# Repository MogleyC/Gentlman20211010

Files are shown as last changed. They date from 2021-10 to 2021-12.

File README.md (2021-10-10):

# Gentlman20211010

해당 제작물의 모든 소유권(소스,정보,파일,개발과정 등)은 (주)프시케가 갖는다.
(주)프시케에서 지정한 소속 관리자 외 일체의 열람/복사/사용을 금한다.
무단 열람/복사/사용이 되는 경우 해당 개인/단체에 법적 책임을 물을 수 있다.
이 외 상세사항 및 권한변경은 (주)프시케의 내부규정에 의거한다.

Gentlman20211010는 주로 Gentlman V6.3을 개발/관리를 위해 제작되었다.
Gentlman V6.3의 주 개발 목표는 다음과 같다.
 - V6.2를 베이스로 한 V6.3 PCB 설계 및 아트웤
 - 무료 툴인 KiCAD를 이용, 툴의 숙달 및 결과물 제작
 - V6.3에 맞는 펌웨어 제작
 - 블루투스 버전인 V6.3B의 개발

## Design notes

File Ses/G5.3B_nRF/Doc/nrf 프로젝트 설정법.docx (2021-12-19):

주간 업무 일지

2021년 12월 6일 ~ 12월 10일

연구개발소장 강신구

# I. 신규 프로젝트 생성 및 설정

## New Solution

### 아무 프로젝트를 만들고 솔루션에서 프로젝트를 remove한다.

### 이후 폴더내에 .emProject 파일을 제외하고 모두 삭제한다.

## New Project

### C/C++ executable for Nordic Semiconductor nRF

### Target Processor : nRF52832_xxAA or nRF52810_xxAA

### Compiler : gcc

### Additional Output Format : hex

### Select files to add to project : Files 및 Import all files and package files 체크 해제. nRF5_SDK파일들을 이용한다.

## Base Project Setting

### Solution or Project → Open Solution in Editor → <project Name>과 </project>사이를 수정

#### 붉은색은 프로젝트 버전 및 nRF칩셋에 맞게 반드시 수정(아래는 nRF52832으로 설정)

#### 연녹색은 소프트디바이스용

<configuration

Name="Common"

arm_architecture="v7EM"

arm_core_type="Cortex-M4"

arm_endian="Little"

arm_fp_abi="Hard"

arm_fpu_type="FPv4-SP-D16"

arm_linker_heap_size="2048"

arm_linker_process_stack_size="0"

arm_linker_stack_size="2048"

arm_linker_treat_warnings_as_errors="No"

arm_simulator_memory_simulation_parameter="RWX 00000000,00100000,FFFFFFFF;RWX 20000000,00010000,CDCDCDCD"

arm_target_device_name="nRF52832_xxAA"

arm_target_interface_type="SWD"

c_preprocessor_definitions="NRF52832_XXAA;NRF52;NRF52_PAN_74;FLOAT_ABI_HARD;CONFIG_GPIO_AS_PINRESET;INITIALIZE_USER_SECTIONS;

c_user_include_directories="$(nRFSdkPath)/modules/nrfx/mdk;$(nRFSdkPath)/components/toolchain/cmsis/include;$(SrcPath);$(SrcPath)/$(nRFSdkVer);"

debug_additional_load_file="$(nRFSdkPath)/components/softdevice/s112/hex/s112_nrf52_7.2.0_softdevice.hex"

debug_register_definition_file="$(nRFSdkPath)/modules/nrfx/mdk/nrf52.svd"

debug_start_from_entry_point_symbol="No"

debug_target_connection="J-Link"

gcc_debugging_level="Level 3"

gcc_entry_point="Reset_Handler"

linker_output_format="hex"

linker_printf_fmt_level="long"

linker_printf_width_precision_supported="Yes"

linker_scanf_fmt_level="long"

linker_section_placement_file="$(nRFSdkPath)/config/$(nRFSdkVer)/ses/flash_placement.xml"

linker_section_placement_macros="FLASH_PH_START=0x0;FLASH_PH_SIZE=0x80000;RAM_PH_START=0x20000000;RAM_PH_SIZE=0x10000;FLASH_START=0x19000;FLASH_SIZE=0x67000;RAM_START=0x200022c8;RAM_SIZE=0xdd38"

linker_section_placements_segments="FLASH1 RX 0x0 0x80000;RAM1 RWX 0x20000000 0x10000"

macros="nRFSdkVer=nrf52832;nRFSdkPath=../../../nRF5_SDK;SrcPath=../../SRC;CMSIS_CONFIG_TOOL=../../../../../../external_tools/cmsisconfig/CMSIS_Configuration_Wizard.jar"

project_directory="nRF52832"

project_type="Executable" />

<folder Name="System Files">

<file file_name="$(StudioDir)/source/thumb_crt0.s" />

<file file_name="$(nRFSdkPath)/modules/nrfx/mdk/ses_startup_nrf52.s" />

<file file_name="$(nRFSdkPath)/modules/nrfx/mdk/ses_startup_nrf_common.s" />

<file file_name="$(nRFSdkPath)/modules/nrfx/mdk/system_nrf52.c" />

</folder>

<folder Name="Application">

<file file_name="$(SrcPath)/main.c" />

<file file_name="$(SrcPath)/$(nRFSdkVer)/sdk_config.h" />

<file file_name="$(SrcPath)/board_config.h" />

</folder>

</project>

## nRF5_SDK용 config setting

### 다음의 두개의 파일을 복사

#### nRF5_SDK 폴더/config/칩셋종류/config/sdk_config.h

#### nRF5_SDK 폴더/config/칩셋종류/ses/flash_placement.xml

### 다음의 위치에 붙여넣기

#### SRC/칩셋종류/

### sdk_config.h의 사용하는 칩셋/모듈에 따라 셋팅 값을 조정해 주어야 한다.

# II. nRF52810 vs nRF52832 셋팅 차이

## 타겟 칩셋 설정

### Project Option → Debugger

#### Target Device : nRF52810_xxAA / nRF52832_xxAA

#### Register Definition File

##### nRF52810 : $(nRFSdkPath)/modules/nrfx/mdk/nrf52810.svd

##### nRF52832 : $(nRFSdkPath)/modules/nrfx/mdk/nrf52.svd

## FPU(부동소수점 유닛)의 유무에 따른 설정

### Project Option → Code Generation

#### ARM FP ABI Type : Soft(nRF52810) / Hard(nRF52832)

#### ARM FPU Type : None(nRF52810) / FPv4-SP-D16(nRF52832)

## 메모리 설정

### Project Option → Runtime Memory Area

#### Heap Size : 2048

#### Main Stack Size : 2048

#### Process Stack Size : 0

#### 위 설정들은 공용으로 사용할 수 있으며, 필요에 따라 칩셋에 맞게 수정한다.

### Project Option → Linker

#### Memory Segments

##### nRF52810 : FLASH1 RX 0x0 0x30000;RAM1 RWX 0x20000000 0x6000

##### nRF52832 : FLASH1 RX 0x0 0x80000;RAM1 RWX 0x20000000 0x10000

#### Memory Placement File

##### $(nRFSdkPath)/config/$(nRFSdkVer)/ses/flash_placement.xml

##### $(nRFSdkVer) 메크로가 제대로 설정되었는지 확인 필요

#### Memory Placement Macros

##### nRF52810 : FLASH_PH_START=0x0;FLASH_PH_SIZE=0x30000;RAM_PH_START=0x20000000;RAM_PH_SIZE=0x6000;FLASH_START=0x19000;FLASH_SIZE=0x17000;RAM_START=0x200022c8;RAM_SIZE=0x3d38

##### nRF52832 : FLASH_PH_START=0x0;FLASH_PH_SIZE=0x80000;RAM_PH_START=0x20000000;RAM_PH_SIZE=0x10000;FLASH_START=0x19000;FLASH_SIZE=0x67000;RAM_START=0x200022c8;RAM_SIZE=0xdd38

## 정의 설정

#### Project Option → Preprocessor → Preprocessor Includes

##### nRF52810 : NRF52810_XXAA;DEVELOP_IN_NRF52832;FLOAT_ABI_SOFT;NRFX_COREDEP_DELAY_US_LOOP_CYCLES=3;

##### nRF52832 : NRF52832_XXAA;NRF52;FLOAT_ABI_HARD;

##### 설정에 맞게 위를 포함시켜야 함

## 시스템 파일 설정

### system file in nRF52810

#### $(nRFSdkPath)/modules/nrfx/mdk/ses_startup_nrf52810.s

#### $(nRFSdkPath)/modules/nrfx/mdk/system_nrf52810.c

### system file in nRF52832

#### $(nRFSdkPath)/modules/nrfx/mdk/ses_startup_nrf52.s

#### $(nRFSdkPath)/modules/nrfx/mdk/system_nrf52.c

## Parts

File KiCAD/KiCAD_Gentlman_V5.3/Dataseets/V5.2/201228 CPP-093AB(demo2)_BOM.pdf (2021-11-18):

Description | Comment | TYPE | MAKER | Quantity | Designator
CHIP CERAMIC CAP | 101K/250V | 2012 | WALSIN, SAMSUNG | 14 | C17, C19, C24, C25, C26, C27, C28, C29, C31, C32, C36, C37, C39, C40
CHIP CERAMIC CAP | 103K/25V | 1608 | WALSIN, SAMSUNG | 0 | C11, C12
CHIP CERAMIC CAP | 103K/25V | 1608 | WALSIN, SAMSUNG | 5 | C23, C38, C45, C50, C51
CHIP CERAMIC CAP | 104Z/25V | 1608 | WALSIN, SAMSUNG | 8 | C1, C2, C3, C4, C5, C7, C13, C14
CHIP CERAMIC CAP | 105Z/6.3V | 1608 | WALSIN, SAMSUNG | 1 | C8
CHIP CERAMIC CAP | 105Z/6.3V | 1608 | WALSIN, SAMSUNG | 0 | C9, C10
CHIP CERAMIC CAP | FS43X105K251EGG | 4532 | WALSIN | 8 | C21, C22, C34, C35, C43, C44, C48, C49
CHIP CERAMIC CAP | TCC1206X7R103K251DT | 3216 | CCTC | 4 | C20, C33, C42, C47
CHIP LED RED | WR106SR-W | 1608 | BRIGHT LED | 7 | D1, D2, D3, D4, D5, D6, D7
CHIP LED RGB | BL-HBHG8JE36K-TRB-T05 | 1615 | BRIGHT LED | 5 | RGB1, RGB2, RGB3, RGB4, RGB5
CHIP RESISTOR | 0RJ | 6432 | WALSIN, SAMSUNG | 1 | R138
CHIP RESISTOR | 1KF | 1608 | WALSIN, SAMSUNG | 29 | .
CHIP RESISTOR | 1KF | 1608 | WALSIN, SAMSUNG | 0 | R23, R24
CHIP RESISTOR | 2.7KF | 1608 | WALSIN, SAMSUNG | 12 | R34, R35, R36, R37, R56, R57, R58, R62, R63, R64, R65, R68
CHIP RESISTOR | 4.7KF | 1608 | WALSIN, SAMSUNG | 2 | R26, R27
CHIP RESISTOR | 8.2KF | 1608 | WALSIN, SAMSUNG | 4 | R45, R71, R95, R125
CHIP RESISTOR | 10KJ | 1608 | WALSIN, SAMSUNG | 1 | R1
CHIP RESISTOR | 10KJ | 1608 | WALSIN, SAMSUNG | 0 | R20, R21, R22
CHIP RESISTOR | 22KJ | 1608 | WALSIN, SAMSUNG | 0 | R25
CHIP RESISTOR | 47RJ | 1608 | WALSIN, SAMSUNG | 5 | R15, R16, R17, R18, R19
CHIP RESISTOR | 100KJ | 1608 | WALSIN, SAMSUNG | 52 | R32, R33, R39, R40, R44, R46, R48, R49, R51, R54, R55, R60, R61, R70, R72, R74, R75, R77, R80, R81, R82, R83, R85, R86, R87, R88, R94, R96, R98, R99, R101, R102, R104, R105, R107, R110, R111, R112, R113, R115, R116, R117, R118, R124, R126, R128, R129, R131, R132, R134, R135, R137
CHIP RESISTOR | 100RJ | 1608 | WALSIN, SAMSUNG | 4 | R43, R69, R93, R123
CHIP RESISTOR | 120RJ | 3216 | WALSIN, SAMSUNG | 4 | R31, R53, R79, R109
CHIP RESISTOR | 150KF | 2012 | WALSIN, SAMSUNG | 8 | R30, R38, R52, R59, R78, R84, R108, R114
CHIP RESISTOR | 270RF | 1608 | WALSIN, SAMSUNG | 1 | R28
CHIP RESISTOR | 390RJ | 1608 | WALSIN, SAMSUNG | 6 | R2, R3, R4, R5, R6, R7
CHIP RESISTOR | 510RF | 1608 | WALSIN, SAMSUNG | 1 | R29
CHIP TRANSISTOR | 2N5401S | SOT-23 | FIRST SILICON | 12 | Q7, Q8, Q13, Q14, Q19, Q20, Q21, Q22, Q31, Q32, Q33, Q34
CHIP TRANSISTOR | 2N5551S | SOT-23 | FIRST SILICON | 24 | Q9, Q10, Q11, Q12, Q15, Q16, Q17, Q18, Q23, Q24, Q25, Q26, Q27, Q28, Q29, Q30, Q35, Q36, Q37, Q38, Q39, Q40, Q41, Q42
CHIP TRANSISTOR | 2SA1981SY | SOT-23 | AUK | 6 | Q1, Q2, Q3, Q4, Q5, Q6
PIN HEADER | SMW2.5MM-7P | DIP-8 | YEONHO ELECTRONICS | 0 | CN1
SMD AMPLIFIER 1W | AP4890 | SOP8 | APLUS | 0 | U4
SMD BUFFER | ULN2003D1013TR | SOP-16 | STMicroelectronics | 1 | U5
SMD DIODE SCHOTTKY | MBRAF3200T3G | SMA | MDD, ON SEMICONDUCTOR | 4 | D8, D9, D10, D11
SMD DIODE TVS | SMBJ15A | SMB | SAMYANG ELECTRONICS | 1 | TVS1
SMD ELECT CAPACITOR | 220uF/6.3V | SC 6.3X5.8 | SAMYOUNG | 7 | C6, C15, C16, C18, C30, C41, C46
SMD INDUCTOR | SC7850D-221K | 7850 | SUHKWANG | 4 | L1, L2, L3, L4
SMD JACK USB C TYPE | USB-TYPE-C-31-M-17 | SMD-6 | Korean-Hroparts-Elec | 1 | CN4
SMD MCU | STM32G070RBT6 | LQFP64 | STMicroelectronics | 1 | U1
SMD MOSFET N-CHANNEL | FDT86246L | SOT223 | FAIRCHILD | 4 | FET1, FET2, FET3, FET4
SMD REGULATOR | LMT117-ADJ | SOT-223 | TGS | 1 | U6
SMD SERIAL FLASH | W25Q32JVSSIQ | SOIC-8(208mil) | WINBOND | 0 | U2
SMD VOICE | VLN1MM04S8X | SOP-8 | SYNOOS | 1 | U3
SMD WAFER | 12505WR-02 | SMD-2 | YEONHO ELECTRONICS | 1 | CN2
SMD WAFER | 12505WR-02 | SMD-2 | YEONHO ELECTRONICS | 0 | CN3
SMD WAFER | 12505WS-08(STRAIGHT) | SMD-8 | YEONHO ELECTRONICS | 1 | CN6
SMD WAFER | 12505WS-09(STRAIGHT) | SMD-9 | YEONHO ELECTRONICS | 1 | CN5
SPEAKER | TDM15A-8-L055C0.5S-0.3D | ASS'Y | NCEI | 1 | SPK1

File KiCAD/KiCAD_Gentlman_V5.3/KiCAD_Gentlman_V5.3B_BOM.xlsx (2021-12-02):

Reference | Quantity | Value | Footprint | Datasheet | Comment | Description | Field4 | MAKER | TYPE | Field5 | PartName | Shop
ANT1 | 1 | ANT | Custom:ANT_PATTERN | .\Dataseets\001-91445_AN91445_Antenna_Design_and_RF_Layout_Guidelines.pdf |  |  | PATTERN
C17 C19 C24 C25 C26 C27 C28 C29 C31 C32 C36 C37 C39 C40 | 14 | CAP_101K_250V_2012 | Custom:C_0805_2012Metric | ~ | CC0805JRNPOYBN101 | CHIP CERAMIC CAP | 101K/250V | YAGEO | 2012 |  |  | https://www.eleparts.co.kr/goods/view?no=9594793
C20 C33 C42 C47 | 4 | CAP_103K_250V_3216 | Custom:C_1206_3216Metric | .\Dataseets\TCC1206X7R103K251DT_10nF_250V_K.pdf | TCC1206X7R103K251DT | CHIP CERAMIC CAP | TCC1206X7R103K251DT | CCTC | 3216 |  |  | https://www.eleparts.co.kr/goods/view?no=8016042
C21 C22 C34 C35 C43 C44 C48 C49 | 8 | CAP_105K_250V_4532 | Custom:C_1812_4532Metric | .\Dataseets\FS43X105K251EGG_1uF_250V_K.pdf | FS43X105K251EGG | CHIP CERAMIC CAP | FS43X105K251EGG | WALSIN | 4532 |  |  | https://www.eleparts.co.kr/goods/view?no=8016951
C23 C38 C45 C50 C51 | 5 | CAP_103K_25V_1608 | Custom:C_0603_1608Metric | ~ | CC0603KRX7R8BB103 | CHIP CERAMIC CAP | 103K/25V | YAGEO | 1608 |  |  | https://www.eleparts.co.kr/goods/view?no=8057789#goodContent_3
C1 C2 C3 C4 C7 C13 C14 | 7 | CAP_104Z_25V_1608 | Custom:C_0603_1608Metric | ~ | CL10B104KA8NNNC | CHIP CERAMIC CAP | 104Z/25V | SAMSUNG ELECTRO-MECHANICS | 1608 |  |  | https://www.eleparts.co.kr/goods/view?no=8010066
C54 | 1 | CAP_4.7uF_1005 | Custom:C_0402_1005Metric | .\Dataseets\MLCC-1837944.pdf | CL05A475KP5NRNC | CHIP CERAMIC CAP | 4.7uF/짹10 | SAMSUNG ELECTRO-MECHANICS | 1005 |  | CL05A475KQ5NRNC | https://www.eleparts.co.kr/goods/view?no=8057798
C56 | 1 | CAP_N.C_1005 | Custom:C_0402_1005Metric | ~ | N.C | CHIP CERAMIC CAP | N.C | MURATA ELECTRONICS | 1005
C52 C53 C55 C57 | 4 | CAP_100nF_1005 | Custom:C_0402_1005Metric | .\Dataseets\GRM155R61H104KE14_01A-1983917.pdf | CL05A104KA5NNNC | CHIP CERAMIC CAP | 100nF/짹10 | SAMSUNG ELECTRO-MECHANICS | 1005 |  | GRM155R61H104KE14D | https://www.eleparts.co.kr/goods/view?no=8011439
C58 | 1 | CAP_1uF_1005 | Custom:C_0402_1005Metric | .\Dataseets\Samsung_MLCC_1837944-1929650.pdf | CL05A105KA5NQNC | CHIP CERAMIC CAP | 1uF/짹10 | SAMSUNG ELECTRO-MECHANICS | 1005 |  | CL05A105KP5NNWC | https://www.eleparts.co.kr/goods/view?no=8010445
C6 C15 C16 C18 C30 C41 C46 | 7 | CAP_220uF_6.3V_SC6.3X5.8 | Custom:C_Elec_6.3x5.8 | ~ | 220uF/6.3V | SMD ELECT CAPACITOR | 220uF/6.3V | SAMYOUNG | SC 6.3X5.8 | SC 6.3X5.8 |  | https://www.eleparts.co.kr/goods/view?no=3369557
C59 C60 | 2 | CAP_12pF_1005 | Custom:C_0402_1005Metric | .\Dataseets\GRM1555C1H120GA01_01A-1982688.pdf | 0402N120G250CT | CHIP CERAMIC CAP | 12pF/NP0/짹2 | WALSIN | 1005 |  | GRM1555C1H120GA01D | https://www.eleparts.co.kr/goods/view?no=9226620
C61 | 1 | CAP_0.8pF_1005 | Custom:C_0402_1005Metric | .\Dataseets\GRM1555C1HR80WA01_01A-1983059.pdf | GRM1555C1HR80WA01D | CHIP CERAMIC CAP | 0.8pF/NP0/짹5 | MURATA ELECTRONICS | 1005 |  | GRM1555C1HR80WA01D | https://www.eleparts.co.kr/goods/view?no=9591919
D1 D2 D3 D4 D5 D6 D7 | 7 | WR106SR-W | Custom:LED_0603_1608Metric | .\Dataseets\WR106SR-W.pdf | WR106SR-W | CHIP LED RED |  | BRIGHT LED | 1608 |  |  | https://www.eleparts.co.kr/goods/view?no=8104608
D8 D9 D10 D11 | 4 | MBRAF3200T3G | Custom:D_SMA | .\Dataseets\MBRAF3200T3_D-2315037.pdf | SS1200-LTP | SMD DIODE SCHOTTKY |  | Micro Commercial | SMA |  |  | https://www.eleparts.co.kr/goods/view?no=1799117
FET1 FET2 FET3 FET4 | 4 | FDT86246L | Custom:SOT-223-3_TabPin2 | .\Dataseets\FDT86246L-D.pdf | FDT86246L | SMD MOSFET N-CHANNEL |  | FAIRCHILD | SOT-223 |  |  | https://www.eleparts.co.kr/goods/view?no=6008399
J1 | 1 | PinHeader2.54mm_7 | Custom:PinHeader_1x07_P2.54mm_Vertical | ~ | PinHeader2.54mm-7P | PIN HEADER | DOWNLOAD | YEONHO ELECTRONICS | DIP-7
J2 | 1 | 12505WR-02 | Custom:12505WR-02 | .\Dataseets\12505-NN.pdf | 12505WR-02 | SMD WAFER | SPEAK1 | YEONHO ELECTRONICS | SMD-2 |  |  | https://www.devicemart.co.kr/goods/view?no=1381566
J4 | 1 | USB-TYPE-C-31-M-17 | Custom:TYPE-C-31-M-17-1 | .\Dataseets\Korean-Hroparts-Elec-TYPE-C-31-M-17.pdf | USB-TYPE-C-31-M-17 | SMD JACK USB C TYPE |  | Korean-Hroparts-Elec | SMD-6 |  |  | https://www.eleparts.co.kr/goods/view?no=7655653
J5 | 1 | 12505WS-09 | Custom:12505WS-09 | .\Dataseets\12505-NN.pdf | 12505WS-09 | SMD WAFER | CH1/CH2/RGB6 | YEONHO ELECTRONICS | SMD-9 |  |  | https://www.devicemart.co.kr/goods/view?no=12012614
J6 | 1 | 12505WS-08 | Custom:12505WS-08 | .\Dataseets\12505-NN.pdf | 12505WS-08 | SMD WAFER | CH3/CH4 | YEONHO ELECTRONICS | SMD-8 |  |  | https://www.devicemart.co.kr/goods/view?no=12012611
J7 | 1 | PinHeader2.54mm_5 | Custom:PinHeader_1x05_P2.54mm_Vertical | ~ | PinHeader2.54mm-5P | PIN HEADER |  |  | DIP-5
JP1 JP2 JP3 | 3 | PinHeader2.54mm-2-Jumper | Custom:PinHeader_1x02_P2.54mm_Vertical | ~ | PinHeader2.54mm-2P | PIN HEADER |  |  | DIP-2
L1 L2 L3 L4 | 4 | SC7850D-221K | Custom:L_SC7850D-221K | http://seokwangcoil.co.kr/7850 | SC7850D-221K | SMD INDUCTOR |  | SUHKWANG | 7850 |  |  | https://www.devicemart.co.kr/goods/view?no=6606
L5 | 1 | L_3.9nH | Custom:L_0402_1005Metric | .\Dataseets\7447840039G-2492425.pdf | LQG15HS3N9C02D | SMD INDUCTOR | 3.9nH/SHF6Ghz/짹5% | MURATA | 1005 |  | 7447840039G | https://www.eleparts.co.kr/goods/view?no=9578079
L6 L8 L10 | 3 | L_10uH | Custom:L_0603_1608Metric | .\Dataseets\JELF243B_0012-1633801.pdf | LQM18FN100M00D | SMD INDUCTOR | 10uH/50mA/짹20% | MURATA | 603 |  | LQM18FN100M00D | https://www.eleparts.co.kr/goods/view?no=7457243
L7 L9 L11 | 3 | L_15nH | Custom:L_0402_1005Metric | .\Dataseets\jti-cat-rf-ind-844822.pdf | LQG15HS15NJ02D | SMD INDUCTOR | 15nH/SHF2.45Ghz/짹10% | MURATA | 1005 |  | L-07C15NKV6T | https://www.eleparts.co.kr/goods/view?no=6591752
Q1 Q2 Q3 Q4 Q5 Q6 | 6 | MMBT200 | Custom:SOT-23 | .\Dataseets\AUKCS02423-1.pdf | MMBT200 | CHIP TRANSISTOR |  | ON SEMICONDUCTOR | SOT-23 |  |  | https://www.eleparts.co.kr/goods/view?no=7467326
Q7 Q8 Q13 Q14 Q19 Q20 Q21 Q22 Q31 Q32 Q33 Q34 | 12 | 2N5401S | Custom:SOT-23 | .\Dataseets\2N5401S.pdf | 2N5401S | CHIP TRANSISTOR |  | FIRST SILICON | SOT-23 |  |  | https://www.eleparts.co.kr/goods/view?no=6561296
Q9 Q10 Q11 Q12 Q15 Q16 Q17 Q18 Q23 Q24 Q25 Q26 Q27 Q28 Q29 Q30 Q35 Q36 Q37 Q38 Q39 Q40 Q41 Q42 | 24 | 2N5551S | Custom:SOT-23 | .\Dataseets\2N5550_1S_Ver2.pdf | 2N5551S | CHIP TRANSISTOR |  | FIRST SILICON | SOT-23 |  |  | https://www.eleparts.co.kr/goods/view?no=6561301
R1 | 1 | R_10KJ | Custom:R_0603_1608Metric | ~ | 10KJ | CHIP RESISTOR | 10KJ | WALSIN, SAMSUNG | 1608
R11 R12 R13 R14 R41 R42 R47 R50 R66 R67 R73 R76 R89 R90 R91 R92 R97 R100 R103 R106 R119 R120 R121 R122 R127 R130 R133 R136 R139 | 29 | R_1KF | Custom:R_0603_1608Metric | ~ | 1KF | CHIP RESISTOR | 1KF | WALSIN, SAMSUNG | 1608 |  |  | https://www.devicemart.co.kr/goods/view?no=6058
R138 | 1 | R_0RJ_6432 | Custom:R_3522_6432Metric | ~ | 0RJ | CHIP RESISTOR | 0RJ | WALSIN, SAMSUNG | 6432 |  |  | https://www.devicemart.co.kr/goods/view?no=1089663
R15 R16 R17 R18 R19 | 5 | R_47RJ | Custom:R_0603_1608Metric | ~ | 47RJ | CHIP RESISTOR | 47RJ | WALSIN, SAMSUNG | 1608
R2 R3 R4 R5 R6 R7 | 6 | R_390RJ | Custom:R_0603_1608Metric | ~ | 390RJ | CHIP RESISTOR | 390RJ | WALSIN, SAMSUNG | 1608
R26 R27 | 2 | R_4.7KF | Custom:R_0603_1608Metric | ~ | 4.7KF | CHIP RESISTOR | 4.7KF | WALSIN, SAMSUNG | 1608
R28 | 1 | R_270RF | Custom:R_0603_1608Metric | ~ | 270RF | CHIP RESISTOR | 270RF | WALSIN, SAMSUNG | 1608
R29 | 1 | R_510RF | Custom:R_0603_1608Metric | ~ | 510RF | CHIP RESISTOR | 510RF | WALSIN, SAMSUNG | 1608
R30 R38 R52 R59 R78 R84 R108 R114 | 8 | R_150KF_2012 | Custom:R_0805_2012Metric | ~ | 150KF | CHIP RESISTOR | 150KF | WALSIN, SAMSUNG | 2012
R31 R53 R79 R109 | 4 | R_120RJ_3216 | Custom:R_1206_3216Metric | ~ | 120RJ | CHIP RESISTOR | 120RJ | WALSIN, SAMSUNG | 3216
R34 R35 R36 R37 R56 R57 R58 R62 R63 R64 R65 R68 | 12 | R_2.7KF | Custom:R_0603_1608Metric | ~ | 2.7KF | CHIP RESISTOR | 2.7KF | WALSIN, SAMSUNG | 1608
R43 R69 R93 R123 | 4 | R_100RJ | Custom:R_0603_1608Metric | ~ | 100RJ | CHIP RESISTOR | 100RJ | WALSIN, SAMSUNG | 1608
R32 R33 R39 R40 R44 R46 R48 R49 R51 R54 R55 R60 R61 R70 R72 R74 R75 R77 R80 R81 R82 R83 R85 R86 R87 R88 R94 R96 R98 R99 R101 R102 R104 R105 R107 R110 R111 R112 R113 R115 R116 R117 R118 R124 R126 R128 R129 R131 R132 R134 R135 R137 | 52 | R_100KJ | Custom:R_0603_1608Metric | ~ | 100KJ | CHIP RESISTOR | 100KJ | WALSIN, SAMSUNG | 1608 |  |  | https://www.devicemart.co.kr/goods/view?no=6133
R45 R71 R95 R125 | 4 | R_8.2KF | Custom:R_0603_1608Metric | ~ | 8.2KF | CHIP RESISTOR | 8.2KF | WALSIN, SAMSUNG | 1608
RGB1 RGB2 RGB3 RGB4 RGB5 | 5 | BL-HBHG8JE36K-TRB-T05 | Custom:LED_RGB_0605 | .\Dataseets\BL-HBHG8JE36K-TRB-T05(3color).pdf | E6C1615RGBC3UDA | CHIP LED RGB |  | EKINGLUX | 1615 |  |  | https://www.ic114.com/WebSite/SITE/sc/00V0.aspx?ID_P=P0085361
SW1 SW2 SW3 SW4 SW5 | 5 | SW_Tact_1105 | Custom:SW_PUSH_6mm_H5mm | https://www.devicemart.co.kr/goods/view?no=34555 | ITS-1105-5mm | SWICH |  | ANY VENDER | DIP_TACT_1105 |  | ITS-1105-5mm | https://www.devicemart.co.kr/goods/view?no=34555
TVS1 | 1 | SMBJ15A | Custom:D_SMB | .\Dataseets\SMBJ.pdf | SMBJ15A | SMD DIODE TVS |  | SAMYANG ELECTRONICS | SMB |  |  | https://www.eleparts.co.kr/goods/view?no=6542453
U1 | 1 | STM32G070RBT6 | Custom:LQFP-64_10x10mm_P0.5mm | http://www.st.com/st-web-ui/static/active/en/resource/technical/document/datasheet/DM00141386.pdf | STM32G070RBT6 | SMD MCU |  | STMicroelectronics | LQFP64 |  |  | https://unit808.com/shop/goods_view.php?id=2967818949&brand=0
U3 | 1 | VLN1MM04S8X | Custom:SOP-8_3.76x4.96mm_P1.27mm | .\Dataseets\VLN1MxxS V1.40 series Data Sheet.pdf | VLN1MM04S8X | SMD VOICE |  | SYNOOS | SOP-8
U5 | 1 | ULN2003D1013TR | Custom:SOIC-16_3.9x9.9mm_P1.27mm | http://www.st.com/content/ccc/resource/technical/document/datasheet/f3/6e/c8/64/4d/b3/4e/38/CD00001244.pdf/files/CD00001244.pdf/jcr:content/translations/en.CD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 | ULN2003D1013TR | SMD BUFFER |  | STMicroelectronics | SOP-16 |  |  | https://www.eleparts.co.kr/goods/view?no=7572406
U6 | 1 | LMT117-ADJ | Custom:SOT-223-3_TabPin2 | .\Dataseets\AX1117_LMT117-ADJ.pdf | LM1117S-ADJ | SMD REGULATOR |  | HTC Korea TAEJIN Tech | SOT-223 |  |  | https://www.eleparts.co.kr/goods/view?no=6559295
U7 | 1 | nRF52832-QFAA | Custom:QFN-48-1EP_6x6mm_P0.4mm_EP4.3x4.3mm | http://infocenter.nordicsemi.com/pdf/nRF52832_PS_v1.4.pdf | nRF52832-QFAA | SMD MCU |  | NORDIC SEMICONDUCTOR | QFN-48 |  | nRF52832-QFAA | https://smartstore.naver.com/ifcompany/products/4967647336
U8 | 1 | nRF52832_DM-SModule | Custom:nRF52832_DM-SModule | http://infocenter.nordicsemi.com/pdf/nRF52832_DM-S_REV1R2.pdf | nRF52832_DM-SModule | SMD BLE MODULE |  | NORDIC SEMICONDUCTOR | nRF52832_DM-SModule |  | nRF52832_DM-SModule | http://dmtech.ne.kr/?page_id=30&uid=27&mod=document&pageid=1
U9 | 1 | nRF52810_PLE52M | Custom:nRF52810_PLE52M | .\Dataseets\DATASHEET_PLE-52M_ver.1.5.pdf | nRF52810_PLE52M | SMD BLE MODULE |  | PROCHILD | nRF52810_PLE52M |  | nRF52810_PLE52M | https://www.devicemart.co.kr/goods/view?no=12538754
Y1 | 1 | Y_32MHz | Custom:Crystal_SMD_2016-4Pin_2.0x1.6mm | .\Dataseets\ECX_1637B-1649431.pdf | X201632MKD4SI | SMD CRYSTAL | 32MHz/Cl:8pF/짹40ppm | Yangxing Tech | 2016 |  | ECS-320-8-37B-7KM-TR | https://www.eleparts.co.kr/goods/view?no=6614084

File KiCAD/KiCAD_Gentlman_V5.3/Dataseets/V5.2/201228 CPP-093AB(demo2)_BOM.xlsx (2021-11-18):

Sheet: Bill of Materials-CPP-093AB_2
Description | Comment | TYPE | MAKER | Quantity | Designator | Quantity검토수식
CHIP CERAMIC CAP | 101K/250V | 2012 | WALSIN, SAMSUNG | 14 | C17, C19, C24, C25, C26, C27, C28, C29, C31, C32, C36, C37, C39, C40 | 14 | OK
CHIP CERAMIC CAP | 103K/25V | 1608 | WALSIN, SAMSUNG | 0 | C11, C12 | 2 | Zero
CHIP CERAMIC CAP | 103K/25V | 1608 | WALSIN, SAMSUNG | 5 | C23, C38, C45, C50, C51 | 5 | OK
CHIP CERAMIC CAP | 104Z/25V | 1608 | WALSIN, SAMSUNG | 8 | C1, C2, C3, C4, C5, C7, C13, C14 | 8 | OK
CHIP CERAMIC CAP | 105Z/6.3V | 1608 | WALSIN, SAMSUNG | 1 | C8 | 1 | OK
CHIP CERAMIC CAP | 105Z/6.3V | 1608 | WALSIN, SAMSUNG | 0 | C9, C10 | 2 | Zero
CHIP CERAMIC CAP | FS43X105K251EGG | 4532 | WALSIN | 8 | C21, C22, C34, C35, C43, C44, C48, C49 | 8 | OK
CHIP CERAMIC CAP | TCC1206X7R103K251DT | 3216 | CCTC | 4 | C20, C33, C42, C47 | 4 | OK
CHIP LED RED | WR106SR-W | 1608 | BRIGHT LED | 7 | D1, D2, D3, D4, D5, D6, D7 | 7 | OK
CHIP LED RGB | BL-HBHG8JE36K-TRB-T05 | 1615 | BRIGHT LED | 5 | RGB1, RGB2, RGB3, RGB4, RGB5 | 5 | OK
CHIP RESISTOR | 0RJ | 6432 | WALSIN, SAMSUNG | 1 | R138 | 1 | OK
CHIP RESISTOR | 1KF | 1608 | WALSIN, SAMSUNG | 29 | R11, R12, R13, R14, R41, R42, R47, R50, R66, R67, R73, R76, R89, R90, R91, R92, R97, R100, R103, R106, R119, R120, R121, R122, R127, R130, R133, R136, R139 | 29 | OK
CHIP RESISTOR | 1KF | 1608 | WALSIN, SAMSUNG | 0 | R23, R24 | 2 | Zero
CHIP RESISTOR | 2.7KF | 1608 | WALSIN, SAMSUNG | 12 | R34, R35, R36, R37, R56, R57, R58, R62, R63, R64, R65, R68 | 12 | OK
CHIP RESISTOR | 4.7KF | 1608 | WALSIN, SAMSUNG | 2 | R26, R27 | 2 | OK
CHIP RESISTOR | 8.2KF | 1608 | WALSIN, SAMSUNG | 4 | R45, R71, R95, R125 | 4 | OK
CHIP RESISTOR | 10KJ | 1608 | WALSIN, SAMSUNG | 1 | R1 | 1 | OK
CHIP RESISTOR | 10KJ | 1608 | WALSIN, SAMSUNG | 0 | R20, R21, R22 | 3 | Zero
CHIP RESISTOR | 22KJ | 1608 | WALSIN, SAMSUNG | 0 | R25 | 1 | Zero
CHIP RESISTOR | 47RJ | 1608 | WALSIN, SAMSUNG | 5 | R15, R16, R17, R18, R19 | 5 | OK
CHIP RESISTOR | 100KJ | 1608 | WALSIN, SAMSUNG | 52 | R32, R33, R39, R40, R44, R46, R48, R49, R51, R54, R55, R60, R61, R70, R72, R74, R75, R77, R80, R81, R82, R83, R85, R86, R87, R88, R94, R96, R98, R99, R101, R102, R104, R105, R107, R110, R111, R112, R113, R115, R116, R117, R118, R124, R126, R128, R129, R131, R132, R134, R135, R137 | 52 | OK
CHIP RESISTOR | 100RJ | 1608 | WALSIN, SAMSUNG | 4 | R43, R69, R93, R123 | 4 | OK
CHIP RESISTOR | 120RJ | 3216 | WALSIN, SAMSUNG | 4 | R31, R53, R79, R109 | 4 | OK
CHIP RESISTOR | 150KF | 2012 | WALSIN, SAMSUNG | 8 | R30, R38, R52, R59, R78, R84, R108, R114 | 8 | OK
CHIP RESISTOR | 270RF | 1608 | WALSIN, SAMSUNG | 1 | R28 | 1 | OK
CHIP RESISTOR | 390RJ | 1608 | WALSIN, SAMSUNG | 6 | R2, R3, R4, R5, R6, R7 | 6 | OK
CHIP RESISTOR | 510RF | 1608 | WALSIN, SAMSUNG | 1 | R29 | 1 | OK
CHIP TRANSISTOR | 2N5401S | SOT-23 | FIRST SILICON | 12 | Q7, Q8, Q13, Q14, Q19, Q20, Q21, Q22, Q31, Q32, Q33, Q34 | 12 | OK
CHIP TRANSISTOR | 2N5551S | SOT-23 | FIRST SILICON | 24 | Q9, Q10, Q11, Q12, Q15, Q16, Q17, Q18, Q23, Q24, Q25, Q26, Q27, Q28, Q29, Q30, Q35, Q36, Q37, Q38, Q39, Q40, Q41, Q42 | 24 | OK
CHIP TRANSISTOR | 2SA1981SY | SOT-23 | AUK | 6 | Q1, Q2, Q3, Q4, Q5, Q6 | 6 | OK
PIN HEADER | SMW2.5MM-7P | DIP-8 | YEONHO ELECTRONICS | 0 | CN1 | 1 | Zero
SMD AMPLIFIER 1W | AP4890 | SOP8 | APLUS | 0 | U4 | 1 | Zero
SMD BUFFER | ULN2003D1013TR | SOP-16 | STMicroelectronics | 1 | U5 | 1 | OK
SMD DIODE SCHOTTKY | MBRAF3200T3G | SMA | MDD, ON SEMICONDUCTOR | 4 | D8, D9, D10, D11 | 4 | OK
SMD DIODE TVS | SMBJ15A | SMB | SAMYANG ELECTRONICS | 1 | TVS1 | 1 | OK
SMD ELECT CAPACITOR | 220uF/6.3V | SC 6.3X5.8 | SAMYOUNG | 7 | C6, C15, C16, C18, C30, C41, C46 | 7 | OK
SMD INDUCTOR | SC7850D-221K | 7850 | SUHKWANG | 4 | L1, L2, L3, L4 | 4 | OK
SMD JACK USB C TYPE | USB-TYPE-C-31-M-17 | SMD-6 | Korean-Hroparts-Elec | 1 | CN4 | 1 | OK
SMD MCU | STM32G070RBT6 | LQFP64 | STMicroelectronics | 1 | U1 | 1 | OK
SMD MOSFET N-CHANNEL | FDT86246L | SOT223 | FAIRCHILD | 4 | FET1, FET2, FET3, FET4 | 4 | OK
SMD REGULATOR | LMT117-ADJ | SOT-223 | TGS | 1 | U6 | 1 | OK
SMD SERIAL FLASH | W25Q32JVSSIQ | SOIC-8(208mil) | WINBOND | 0 | U2 | 1 | Zero
SMD VOICE | VLN1MM04S8X | SOP-8 | SYNOOS | 1 | U3 | 1 | OK
SMD WAFER | 12505WR-02 | SMD-2 | YEONHO ELECTRONICS | 1 | CN2 | 1 | OK
SMD WAFER | 12505WR-02 | SMD-2 | YEONHO ELECTRONICS | 0 | CN3 | 1 | Zero
SMD WAFER | 12505WS-08(STRAIGHT) | SMD-8 | YEONHO ELECTRONICS | 1 | CN6 | 1 | OK
SMD WAFER | 12505WS-09(STRAIGHT) | SMD-9 | YEONHO ELECTRONICS | 1 | CN5 | 1 | OK
SPEAKER | TDM15A-8-L055C0.5S-0.3D | ASS'Y | NCEI | 1 | SPK1 | 1 | OK
 |  |  |  |  |  | 14 | ZeroSum

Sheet: Bill of Materials-CPP-093AB
Description | Comment | TYPE | MAKER | Quantity | Designator
CHIP CERAMIC CAP | 101K/250V | 2012 | WALSIN, SAMSUNG | 14 | C17, C19, C24, C25, C26, C27, C28, C29, C31, C32, C36, C37, C39, C40
CHIP CERAMIC CAP | 103K/25V | 1608 | WALSIN, SAMSUNG | 7 | C11, C12, C23, C38, C45, C50, C51
CHIP CERAMIC CAP | 104Z/25V | 1608 | WALSIN, SAMSUNG | 8 | C1, C2, C3, C4, C5, C7, C13, C14
CHIP CERAMIC CAP | 105Z/6.3V | 1608 | WALSIN, SAMSUNG | 3 | C8, C9, C10
CHIP CERAMIC CAP | FS43X105K251EGG | 4532 | WALSIN | 8 | C21, C22, C34, C35, C43, C44, C48, C49
CHIP CERAMIC CAP | TCC1206X7R103K251DT | 3216 | CCTC | 4 | C20, C33, C42, C47
CHIP LED RED | WR106SR-W | 1608 | BRIGHT LED | 7 | D1, D2, D3, D4, D5, D6, D7
CHIP LED RGB | BL-HBHG8JE36K-TRB-T05 | 1615 | BRIGHT LED | 5 | RGB1, RGB2, RGB3, RGB4, RGB5
CHIP RESISTOR | 0RJ | 6432 | WALSIN, SAMSUNG | 1 | R138
CHIP RESISTOR | 1KF | 1608 | WALSIN, SAMSUNG | 31 | R11, R12, R13, R14, R23, R24, R41, R42, R47, R50, R66, R67, R73, R76, R89, R90, R91, R92, R97, R100, R103, R106, R119, R120, R121, R122, R127, R130, R133, R136, R139
CHIP RESISTOR | 2.7KF | 1608 | WALSIN, SAMSUNG | 12 | R34, R35, R36, R37, R56, R57, R58, R62, R63, R64, R65, R68
CHIP RESISTOR | 4.7KF | 1608 | WALSIN, SAMSUNG | 2 | R26, R27
CHIP RESISTOR | 8.2KF | 1608 | WALSIN, SAMSUNG | 4 | R45, R71, R95, R125
CHIP RESISTOR | 10KJ | 1608 | WALSIN, SAMSUNG | 4 | R1, R20, R21, R22
CHIP RESISTOR | 22KJ | 1608 | WALSIN, SAMSUNG | 1 | R25
CHIP RESISTOR | 47RJ | 1608 | WALSIN, SAMSUNG | 5 | R15, R16, R17, R18, R19
CHIP RESISTOR | 100KJ | 1608 | WALSIN, SAMSUNG | 52 | R32, R33, R39, R40, R44, R46, R48, R49, R51, R54, R55, R60, R61, R70, R72, R74, R75, R77, R80, R81, R82, R83, R85, R86, R87, R88, R94, R96, R98, R99, R101, R102, R104, R105, R107, R110, R111, R112, R113, R115, R116, R117, R118, R124, R126, R128, R129, R131, R132, R134, R135, R137
CHIP RESISTOR | 100RJ | 1608 | WALSIN, SAMSUNG | 4 | R43, R69, R93, R123
CHIP RESISTOR | 120RJ | 3216 | WALSIN, SAMSUNG | 4 | R31, R53, R79, R109
CHIP RESISTOR | 150KF | 2012 | WALSIN, SAMSUNG | 8 | R30, R38, R52, R59, R78, R84, R108, R114
CHIP RESISTOR | 270RF | 1608 | WALSIN, SAMSUNG | 1 | R28
CHIP RESISTOR | 390RJ | 1608 | WALSIN, SAMSUNG | 6 | R2, R3, R4, R5, R6, R7
CHIP RESISTOR | 510RF | 1608 | WALSIN, SAMSUNG | 1 | R29
CHIP TRANSISTOR | 2N5401S | SOT-23 | FIRST SILICON | 12 | Q7, Q8, Q13, Q14, Q19, Q20, Q21, Q22, Q31, Q32, Q33, Q34
CHIP TRANSISTOR | 2N5551S | SOT-23 | FIRST SILICON | 24 | Q9, Q10, Q11, Q12, Q15, Q16, Q17, Q18, Q23, Q24, Q25, Q26, Q27, Q28, Q29, Q30, Q35, Q36, Q37, Q38, Q39, Q40, Q41, Q42
CHIP TRANSISTOR | 2SA1981SY | SOT-23 | AUK | 6 | Q1, Q2, Q3, Q4, Q5, Q6
PIN HEADER | SMW2.5MM-7P | DIP-8 | YEONHO ELECTRONICS | 0 | CN1
SMD AMPLIFIER 1W | AP4890 | SOP8 | APLUS | 0 | U4
SMD BUFFER | ULN2003D1013TR | SOP-16 | STMicroelectronics | 1 | U5
SMD DIODE SCHOTTKY | MBRAF3200T3G | SMA | MDD, ON SEMICONDUCTOR | 4 | D8, D9, D10, D11
SMD DIODE TVS | SMBJ15A | SMB | SAMYANG ELECTRONICS | 1 | TVS1
SMD ELECT CAPACITOR | 220uF/6.3V | SC 6.3X5.8 | SAMYOUNG | 7 | C6, C15, C16, C18, C30, C41, C46
SMD INDUCTOR | SC7850D-221K | 7850 | SUHKWANG | 4 | L1, L2, L3, L4
SMD JACK USB C TYPE | USB-TYPE-C-31-M-17 | SMD-6 | Korean-Hroparts-Elec | 1 | CN4
SMD MCU | STM32G070RBT6 | LQFP64 | STMicroelectronics | 1 | U1
SMD MOSFET N-CHANNEL | FDT86246L | SOT223 | FAIRCHILD | 4 | FET1, FET2, FET3, FET4
SMD REGULATOR | LMT117-ADJ | SOT-223 | TGS | 1 | U6
SMD SERIAL FLASH | W25Q32JVSSIQ | SOIC-8(208mil) | WINBOND | 0 | U2
SMD VOICE | VLN1MM04S8X | SOP-8 | SYNOOS | 1 | U3
SMD WAFER | 12505WR-02 | SMD-2 | YEONHO ELECTRONICS | 2 | CN2, CN3
SMD WAFER | 12505WS-08(STRAIGHT) | SMD-8 | YEONHO ELECTRONICS | 1 | CN6
SMD WAFER | 12505WS-09(STRAIGHT) | SMD-9 | YEONHO ELECTRONICS | 1 | CN5
SPEAKER | TDM15A-8-L055C0.5S-0.3D | ASS'Y | NCEI | 1 | SPK1

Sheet: bom
Description | Comment | TYPE | MAKER | Quantity | Designator
CHIP CERAMIC CAP | 101K/250V | 2012 | WALSIN, SAMSUNG | 14 | C17 C19 C24 C25 C26 C27 C28 C29 C31 C32 C36 C37 C39 C40 | CHIP CERAMIC CAP101K/250V2012WALSIN, SAMSUNG | 3 | TRUE | TRUE
CHIP CERAMIC CAP | 103K/25V | 1608 | WALSIN, SAMSUNG | 7 | C11 C12 C23 C38 C45 C50 C51 | CHIP CERAMIC CAP103K/25V1608WALSIN, SAMSUNG | 2 | TRUE | TRUE
CHIP CERAMIC CAP | 104Z/25V | 1608 | WALSIN, SAMSUNG | 8 | C1 C2 C3 C4 C5 C7 C13 C14 | CHIP CERAMIC CAP104Z/25V1608WALSIN, SAMSUNG | 6 | TRUE | TRUE
CHIP CERAMIC CAP | 105Z/6.3V | 1608 | WALSIN, SAMSUNG | 3 | C8 C9 C10 | CHIP CERAMIC CAP105Z/6.3V1608WALSIN, SAMSUNG | 8 | TRUE | TRUE
CHIP CERAMIC CAP | FS43X105K251EGG | 4532 | WALSIN | 8 | C21 C22 C34 C35 C43 C44 C48 C49 | CHIP CERAMIC CAPFS43X105K251EGG4532WALSIN | 5 | TRUE | TRUE
CHIP CERAMIC CAP | TCC1206X7R103K251DT | 3216 | CCTC | 4 | C20 C33 C42 C47 | CHIP CERAMIC CAPTCC1206X7R103K251DT3216CCTC | 4 | TRUE | TRUE
CHIP LED RED | WR106SR-W | 1608 | BRIGHT LED | 7 | D1 D2 D3 D4 D5 D6 D7 | CHIP LED REDWR106SR-W1608BRIGHT LED | 14 | TRUE | TRUE
CHIP LED RGB | BL-HBHG8JE36K-TRB-T05 | 1615 | BRIGHT LED | 5 | RGB1 RGB2 RGB3 RGB4 RGB5 | CHIP LED RGBBL-HBHG8JE36K-TRB-T051615BRIGHT LED | 38 | TRUE | TRUE
CHIP RESISTOR | 0RJ | 6432 | WALSIN, SAMSUNG | 1 | R138 | CHIP RESISTOR0RJ6432WALSIN, SAMSUNG | 24 | TRUE | TRUE
CHIP RESISTOR | 1KF | 1608 | WALSIN, SAMSUNG | 31 | R11 R12 R13 R14 R23 R24 R41 R42 R47 R50 R66 R67 R73 R76 R89 R90 R91 R92 R97 R100 R103 R106 R119 R120 R121 R122 R127 R130 R133 R136 R139 | CHIP RESISTOR1KF1608WALSIN, SAMSUNG | 23 | TRUE | TRUE
CHIP RESISTOR | 2.7KF | 1608 | WALSIN, SAMSUNG | 12 | R34 R35 R36 R37 R56 R57 R58 R62 R63 R64 R65 R68 | CHIP RESISTOR2.7KF1608WALSIN, SAMSUNG | 33 | TRUE | TRUE
CHIP RESISTOR | 4.7KF | 1608 | WALSIN, SAMSUNG | 2 | R26 R27 | CHIP RESISTOR4.7KF1608WALSIN, SAMSUNG | 28 | TRUE | TRUE
CHIP RESISTOR | 8.2KF | 1608 | WALSIN, SAMSUNG | 4 | R45 R71 R95 R125 | CHIP RESISTOR8.2KF1608WALSIN, SAMSUNG | 36 | TRUE | TRUE
CHIP RESISTOR | 10KJ | 1608 | WALSIN, SAMSUNG | 4 | R1 R20 R21 R22 | CHIP RESISTOR10KJ1608WALSIN, SAMSUNG | 22 | TRUE | TRUE
CHIP RESISTOR | 22KJ | 1608 | WALSIN, SAMSUNG | 1 | R25 | CHIP RESISTOR22KJ1608WALSIN, SAMSUNG | 27 | TRUE | TRUE
CHIP RESISTOR | 47RJ | 1608 | WALSIN, SAMSUNG | 5 | R15 R16 R17 R18 R19 | CHIP RESISTOR47RJ1608WALSIN, SAMSUNG | 25 | TRUE | TRUE
CHIP RESISTOR | 100KJ | 1608 | WALSIN, SAMSUNG | 52 | R32 R33 R39 R40 R44 R46 R48 R49 R51 R54 R55 R60 R61 R70 R72 R74 R75 R77 R80 R81 R82 R83 R85 R86 R87 R88 R94 R96 R98 R99 R101 R102 R104 R105 R107 R110 R111 R112 R113 R115 R116 R117 R118 R124 R126 R128 R129 R131 R132 R134 R135 R137 | CHIP RESISTOR100KJ1608WALSIN, SAMSUNG | 35 | TRUE | TRUE
CHIP RESISTOR | 100RJ | 1608 | WALSIN, SAMSUNG | 4 | R43 R69 R93 R123 | CHIP RESISTOR100RJ1608WALSIN, SAMSUNG | 34 | TRUE | TRUE
CHIP RESISTOR | 120RJ | 3216 | WALSIN, SAMSUNG | 4 | R31 R53 R79 R109 | CHIP RESISTOR120RJ3216WALSIN, SAMSUNG | 32 | TRUE | TRUE
CHIP RESISTOR | 150KF | 2012 | WALSIN, SAMSUNG | 8 | R30 R38 R52 R59 R78 R84 R108 R114 | CHIP RESISTOR150KF2012WALSIN, SAMSUNG | 31 | TRUE | TRUE
CHIP RESISTOR | 270RF | 1608 | WALSIN, SAMSUNG | 1 | R28 | CHIP RESISTOR270RF1608WALSIN, SAMSUNG | 29 | TRUE | TRUE
CHIP RESISTOR | 390RJ | 1608 | WALSIN, SAMSUNG | 6 | R2 R3 R4 R5 R6 R7 | CHIP RESISTOR390RJ1608WALSIN, SAMSUNG | 26 | TRUE | TRUE
CHIP RESISTOR | 510RF | 1608 | WALSIN, SAMSUNG | 1 | R29 | CHIP RESISTOR510RF1608WALSIN, SAMSUNG | 30 | TRUE | TRUE
CHIP TRANSISTOR | 2N5401S | SOT-23 | FIRST SILICON | 12 | Q7 Q8 Q13 Q14 Q19 Q20 Q21 Q22 Q31 Q32 Q33 Q34 | CHIP TRANSISTOR2N5401SSOT-23FIRST SILICON | 20 | TRUE | TRUE
CHIP TRANSISTOR | 2N5551S | SOT-23 | FIRST SILICON | 24 | Q9 Q10 Q11 Q12 Q15 Q16 Q17 Q18 Q23 Q24 Q25 Q26 Q27 Q28 Q29 Q30 Q35 Q36 Q37 Q38 Q39 Q40 Q41 Q42 | CHIP TRANSISTOR2N5551SSOT-23FIRST SILICON | 21 | TRUE | TRUE
CHIP TRANSISTOR | 2SA1981SY | SOT-23 | AUK | 6 | Q1 Q2 Q3 Q4 Q5 Q6 | CHIP TRANSISTOR2SA1981SYSOT-23AUK | 19 | TRUE | TRUE
PIN HEADER | SMW2.5MM-7P | DIP-8 | YEONHO ELECTRONICS | 1 | CN1 | PIN HEADERSMW2.5MM-7PDIP-8YEONHO ELECTRONICS | 9 | TRUE | TRUE
SMD AMPLIFIER 1W | AP4890 | SOP8 | APLUS | 1 | U4 | SMD AMPLIFIER 1WAP4890SOP8APLUS | 43 | TRUE | TRUE
SMD BUFFER | ULN2003D1013TR | SOP-16 | STMicroelectronics | 1 | U5 | SMD BUFFERULN2003D1013TRSOP-16STMicroelectronics | 44 | TRUE | TRUE
SMD DIODE SCHOTTKY | MBRAF3200T3G | SMA | MDD, ON SEMICONDUCTOR | 4 | D8 D9 D10 D11 | SMD DIODE SCHOTTKYMBRAF3200T3GSMAMDD, ON SEMICONDUCTOR | 15 | TRUE | TRUE
SMD DIODE TVS | SMBJ15A | SMB | SAMYANG ELECTRONICS | 1 | TVS1 | SMD DIODE TVSSMBJ15ASMBSAMYANG ELECTRONICS | 39 | TRUE | TRUE
SMD ELECT CAPACITOR | 220uF/6.3V | SC 6.3X5.8 | SAMYOUNG | 7 | C6 C15 C16 C18 C30 C41 C46 | SMD ELECT CAPACITOR220uF/6.3VSC 6.3X5.8SAMYOUNG | 7 | TRUE | TRUE
SMD INDUCTOR | SC7850D-221K | 7850 | SUHKWANG | 4 | L1 L2 L3 L4 | SMD INDUCTORSC7850D-221K7850SUHKWANG | 18 | TRUE | TRUE
SMD JACK USB C TYPE | USB-TYPE-C-31-M-17 | SMD-6 | Korean-Hroparts-Elec | 1 | CN4 | SMD JACK USB C TYPEUSB-TYPE-C-31-M-17SMD-6Korean-Hroparts-Elec | 11 | TRUE | TRUE
SMD MCU | STM32G070RBT6 | LQFP64 | STMicroelectronics | 1 | U1 | SMD MCUSTM32G070RBT6LQFP64STMicroelectronics | 40 | TRUE | TRUE
SMD MOSFET N-CHANNEL | FDT86246L | SOT-223 | FAIRCHILD | 4 | FET1 FET2 FET3 FET4 | SMD MOSFET N-CHANNELFDT86246LSOT-223FAIRCHILD | 16 | TRUE | TRUE
SMD REGULATOR | LMT117-ADJ | SOT-223 | TGS | 1 | U6 | SMD REGULATORLMT117-ADJSOT-223TGS | 45 | TRUE | TRUE
SMD SERIAL FLASH | W25Q32JVSSIQ | SOIC-8(208mil) | WINBOND | 1 | U2 | SMD SERIAL FLASHW25Q32JVSSIQSOIC-8(208mil)WINBOND | 41 | TRUE | TRUE
SMD VOICE | VLN1MM04S8X | SOP-8 | SYNOOS | 1 | U3 | SMD VOICEVLN1MM04S8XSOP-8SYNOOS | 42 | TRUE | TRUE
SMD WAFER | 12505WR-02 | SMD-2 | YEONHO ELECTRONICS | 2 | CN2 CN3 | SMD WAFER12505WR-02SMD-2YEONHO ELECTRONICS | 10 | TRUE | TRUE
SMD WAFER | 12505WS-08 | SMD-8 | YEONHO ELECTRONICS | 1 | CN6 | SMD WAFER12505WS-08SMD-8YEONHO ELECTRONICS | 13 | TRUE | TRUE
SMD WAFER | 12505WS-09 | SMD-9 | YEONHO ELECTRONICS | 1 | CN5 | SMD WAFER12505WS-09SMD-9YEONHO ELECTRONICS | 12 | TRUE | TRUE
SPEAKER | TDM15A-8-L055C0.5S-0.3D | ASS'Y | NCEI | 1 | SPK1 | SPEAKERTDM15A-8-L055C0.5S-0.3DASS'YNCEI | #N/A | #N/A | #N/A

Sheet: Lib
 |  |  |  | 0 0 50 H I C CNN
1 | CHIP CERAMIC CAP | 4 | Description | F4 "CHIP CERAMIC CAP" 0 0 50 H I C CNN "Description"
1 | 101K/250V | 5 | Comment | F5 "101K/250V" 0 0 50 H I C CNN "Comment"
1 | 2012 | 6 | TYPE | F6 "2012" 0 0 50 H I C CNN "TYPE"
1 | WALSIN, SAMSUNG | 7 | MAKER | F7 "WALSIN, SAMSUNG" 0 0 50 H I C CNN "MAKER"
2 | CHIP CERAMIC CAP | 4 | Description | F4 "CHIP CERAMIC CAP" 0 0 50 H I C CNN "Description"
2 | 103K/25V | 5 | Comment | F5 "103K/25V" 0 0 50 H I C CNN "Comment"
2 | 1608 | 6 | TYPE | F6 "1608" 0 0 50 H I C CNN "TYPE"
2 | WALSIN, SAMSUNG | 7 | MAKER | F7 "WALSIN, SAMSUNG" 0 0 50 H I C CNN "MAKER"
3 | CHIP CERAMIC CAP | 4 | Description | F4 "CHIP CERAMIC CAP" 0 0 50 H I C CNN "Description"
3 | 104Z/25V | 5 | Comment | F5 "104Z/25V" 0 0 50 H I C CNN "Comment"
3 | 1608 | 6 | TYPE | F6 "1608" 0 0 50 H I C CNN "TYPE"
3 | WALSIN, SAMSUNG | 7 | MAKER | F7 "WALSIN, SAMSUNG" 0 0 50 H I C CNN "MAKER"
4 | CHIP CERAMIC CAP | 4 | Description | F4 "CHIP CERAMIC CAP" 0 0 50 H I C CNN "Description"
4 | 105Z/6.3V | 5 | Comment | F5 "105Z/6.3V" 0 0 50 H I C CNN "Comment"
4 | 1608 | 6 | TYPE | F6 "1608" 0 0 50 H I C CNN "TYPE"
4 | WALSIN, SAMSUNG | 7 | MAKER | F7 "WALSIN, SAMSUNG" 0 0 50 H I C CNN "MAKER"
5 | CHIP CERAMIC CAP | 4 | Description | F4 "CHIP CERAMIC CAP" 0 0 50 H I C CNN "Description"
5 | FS43X105K251EGG | 5 | Comment | F5 "FS43X105K251EGG" 0 0 50 H I C CNN "Comment"
5 | 4532 | 6 | TYPE | F6 "4532" 0 0 50 H I C CNN "TYPE"
5 | WALSIN | 7 | MAKER | F7 "WALSIN" 0 0 50 H I C CNN "MAKER"
6 | CHIP CERAMIC CAP | 4 | Description | F4 "CHIP CERAMIC CAP" 0 0 50 H I C CNN "Description"
6 | TCC1206X7R103K251DT | 5 | Comment | F5 "TCC1206X7R103K251DT" 0 0 50 H I C CNN "Comment"
6 | 3216 | 6 | TYPE | F6 "3216" 0 0 50 H I C CNN "TYPE"
6 | CCTC | 7 | MAKER | F7 "CCTC" 0 0 50 H I C CNN "MAKER"
7 | CHIP LED RED | 4 | Description | F4 "CHIP LED RED" 0 0 50 H I C CNN "Description"
7 | WR106SR-W | 5 | Comment | F5 "WR106SR-W" 0 0 50 H I C CNN "Comment"
7 | 1608 | 6 | TYPE | F6 "1608" 0 0 50 H I C CNN "TYPE"
7 | BRIGHT LED | 7 | MAKER | F7 "BRIGHT LED" 0 0 50 H I C CNN "MAKER"
8 | CHIP LED RGB | 4 | Description | F4 "CHIP LED RGB" 0 0 50 H I C CNN "Description"
8 | BL-HBHG8JE36K-TRB-T05 | 5 | Comment | F5 "BL-HBHG8JE36K-TRB-T05" 0 0 50 H I C CNN "Comment"
8 | 1615 | 6 | TYPE | F6 "1615" 0 0 50 H I C CNN "TYPE"
8 | BRIGHT LED | 7 | MAKER | F7 "BRIGHT LED" 0 0 50 H I C CNN "MAKER"
9 | CHIP RESISTOR | 5 | Description | F5 "CHIP RESISTOR" 0 0 50 H I C CNN "Description"
9 | 0RJ | 6 | Comment | F6 "0RJ" 0 0 50 H I C CNN "Comment"
9 | 6432 | 7 | TYPE | F7 "6432" 0 0 50 H I C CNN "TYPE"
9 | WALSIN, SAMSUNG | 8 | MAKER | F8 "WALSIN, SAMSUNG" 0 0 50 H I C CNN "MAKER"
10 | CHIP RESISTOR | 5 | Description | F5 "CHIP RESISTOR" 0 0 50 H I C CNN "Description"
10 | 1KF | 6 | Comment | F6 "1KF" 0 0 50 H I C CNN "Comment"
10 | 1608 | 7 | TYPE | F7 "1608" 0 0 50 H I C CNN "TYPE"
10 | WALSIN, SAMSUNG | 8 | MAKER | F8 "WALSIN, SAMSUNG" 0 0 50 H I C CNN "MAKER"
11 | CHIP RESISTOR | 5 | Description | F5 "CHIP RESISTOR" 0 0 50 H I C CNN "Description"
11 | 2.7KF | 6 | Comment | F6 "2.7KF" 0 0 50 H I C CNN "Comment"
11 | 1608 | 7 | TYPE | F7 "1608" 0 0 50 H I C CNN "TYPE"
11 | WALSIN, SAMSUNG | 8 | MAKER | F8 "WALSIN, SAMSUNG" 0 0 50 H I C CNN "MAKER"
12 | CHIP RESISTOR | 5 | Description | F5 "CHIP RESISTOR" 0 0 50 H I C CNN "Description"
12 | 4.7KF | 6 | Comment | F6 "4.7KF" 0 0 50 H I C CNN "Comment"
12 | 1608 | 7 | TYPE | F7 "1608" 0 0 50 H I C CNN "TYPE"
12 | WALSIN, SAMSUNG | 8 | MAKER | F8 "WALSIN, SAMSUNG" 0 0 50 H I C CNN "MAKER"
13 | CHIP RESISTOR | 5 | Description | F5 "CHIP RESISTOR" 0 0 50 H I C CNN "Description"
13 | 8.2KF | 6 | Comment | F6 "8.2KF" 0 0 50 H I C CNN "Comment"
13 | 1608 | 7 | TYPE | F7 "1608" 0 0 50 H I C CNN "TYPE"
13 | WALSIN, SAMSUNG | 8 | MAKER | F8 "WALSIN, SAMSUNG" 0 0 50 H I C CNN "MAKER"
14 | CHIP RESISTOR | 5 | Description | F5 "CHIP RESISTOR" 0 0 50 H I C CNN "Description"
14 | 10KJ | 6 | Comment | F6 "10KJ" 0 0 50 H I C CNN "Comment"
14 | 1608 | 7 | TYPE | F7 "1608" 0 0 50 H I C CNN "TYPE"
14 | WALSIN, SAMSUNG | 8 | MAKER | F8 "WALSIN, SAMSUNG" 0 0 50 H I C CNN "MAKER"
15 | CHIP RESISTOR | 5 | Description | F5 "CHIP RESISTOR" 0 0 50 H I C CNN "Description"
15 | 22KJ | 6 | Comment | F6 "22KJ" 0 0 50 H I C CNN "Comment"
15 | 1608 | 7 | TYPE | F7 "1608" 0 0 50 H I C CNN "TYPE"
15 | WALSIN, SAMSUNG | 8 | MAKER | F8 "WALSIN, SAMSUNG" 0 0 50 H I C CNN "MAKER"
16 | CHIP RESISTOR | 5 | Description | F5 "CHIP RESISTOR" 0 0 50 H I C CNN "Description"
16 | 47RJ | 6 | Comment | F6 "47RJ" 0 0 50 H I C CNN "Comment"
16 | 1608 | 7 | TYPE | F7 "1608" 0 0 50 H I C CNN "TYPE"
16 | WALSIN, SAMSUNG | 8 | MAKER | F8 "WALSIN, SAMSUNG" 0 0 50 H I C CNN "MAKER"
17 | CHIP RESISTOR | 5 | Description | F5 "CHIP RESISTOR" 0 0 50 H I C CNN "Description"
17 | 100KJ | 6 | Comment | F6 "100KJ" 0 0 50 H I C CNN "Comment"
17 | 1608 | 7 | TYPE | F7 "1608" 0 0 50 H I C CNN "TYPE"
17 | WALSIN, SAMSUNG | 8 | MAKER | F8 "WALSIN, SAMSUNG" 0 0 50 H I C CNN "MAKER"
18 | CHIP RESISTOR | 5 | Description | F5 "CHIP RESISTOR" 0 0 50 H I C CNN "Description"
18 | 100RJ | 6 | Comment | F6 "100RJ" 0 0 50 H I C CNN "Comment"
18 | 1608 | 7 | TYPE | F7 "1608" 0 0 50 H I C CNN "TYPE"
18 | WALSIN, SAMSUNG | 8 | MAKER | F8 "WALSIN, SAMSUNG" 0 0 50 H I C CNN "MAKER"
19 | CHIP RESISTOR | 5 | Description | F5 "CHIP RESISTOR" 0 0 50 H I C CNN "Description"
19 | 120RJ | 6 | Comment | F6 "120RJ" 0 0 50 H I C CNN "Comment"
19 | 3216 | 7 | TYPE | F7 "3216" 0 0 50 H I C CNN "TYPE"
19 | WALSIN, SAMSUNG | 8 | MAKER | F8 "WALSIN, SAMSUNG" 0 0 50 H I C CNN "MAKER"
20 | CHIP RESISTOR | 5 | Description | F5 "CHIP RESISTOR" 0 0 50 H I C CNN "Description"
20 | 150KF | 6 | Comment | F6 "150KF" 0 0 50 H I C CNN "Comment"
20 | 2012 | 7 | TYPE | F7 "2012" 0 0 50 H I C CNN "TYPE"
20 | WALSIN, SAMSUNG | 8 | MAKER | F8 "WALSIN, SAMSUNG" 0 0 50 H I C CNN "MAKER"
21 | CHIP RESISTOR | 5 | Description | F5 "CHIP RESISTOR" 0 0 50 H I C CNN "Description"
21 | 270RF | 6 | Comment | F6 "270RF" 0 0 50 H I C CNN "Comment"
21 | 1608 | 7 | TYPE | F7 "1608" 0 0 50 H I C CNN "TYPE"
21 | WALSIN, SAMSUNG | 8 | MAKER | F8 "WALSIN, SAMSUNG" 0 0 50 H I C CNN "MAKER"
22 | CHIP RESISTOR | 5 | Description | F5 "CHIP RESISTOR" 0 0 50 H I C CNN "Description"
22 | 390RJ | 6 | Comment | F6 "390RJ" 0 0 50 H I C CNN "Comment"
22 | 1608 | 7 | TYPE | F7 "1608" 0 0 50 H I C CNN "TYPE"
22 | WALSIN, SAMSUNG | 8 | MAKER | F8 "WALSIN, SAMSUNG" 0 0 50 H I C CNN "MAKER"
23 | CHIP RESISTOR | 5 | Description | F5 "CHIP RESISTOR" 0 0 50 H I C CNN "Description"
23 | 510RF | 6 | Comment | F6 "510RF" 0 0 50 H I C CNN "Comment"
23 | 1608 | 7 | TYPE | F7 "1608" 0 0 50 H I C CNN "TYPE"
23 | WALSIN, SAMSUNG | 8 | MAKER | F8 "WALSIN, SAMSUNG" 0 0 50 H I C CNN "MAKER"
24 | CHIP TRANSISTOR | 4 | Description | F4 "CHIP TRANSISTOR" 0 0 50 H I C CNN "Description"
24 | 2N5401S | 5 | Comment | F5 "2N5401S" 0 0 50 H I C CNN "Comment"
24 | SOT-23 | 6 | TYPE | F6 "SOT-23" 0 0 50 H I C CNN "TYPE"
24 | FIRST SILICON | 7 | MAKER | F7 "FIRST SILICON" 0 0 50 H I C CNN "MAKER"
25 | CHIP TRANSISTOR | 4 | Description | F4 "CHIP TRANSISTOR" 0 0 50 H I C CNN "Description"
25 | 2N5551S | 5 | Comment | F5 "2N5551S" 0 0 50 H I C CNN "Comment"
25 | SOT-23 | 6 | TYPE | F6 "SOT-23" 0 0 50 H I C CNN "TYPE"
25 | FIRST SILICON | 7 | MAKER | F7 "FIRST SILICON" 0 0 50 H I C CNN "MAKER"
26 | CHIP TRANSISTOR | 4 | Description | F4 "CHIP TRANSISTOR" 0 0 50 H I C CNN "Description"
26 | 2SA1981SY | 5 | Comment | F5 "2SA1981SY" 0 0 50 H I C CNN "Comment"
26 | SOT-23 | 6 | TYPE | F6 "SOT-23" 0 0 50 H I C CNN "TYPE"
26 | AUK | 7 | MAKER | F7 "AUK" 0 0 50 H I C CNN "MAKER"
27 | PIN HEADER | 4 | Description | F4 "PIN HEADER" 0 0 50 H I C CNN "Description"
27 | SMW2.5MM-7P | 5 | Comment | F5 "SMW2.5MM-7P" 0 0 50 H I C CNN "Comment"
27 | DIP-8 | 6 | TYPE | F6 "DIP-8" 0 0 50 H I C CNN "TYPE"
27 | YEONHO ELECTRONICS | 7 | MAKER | F7 "YEONHO ELECTRONICS" 0 0 50 H I C CNN "MAKER"
28 | SMD AMPLIFIER 1W | 4 | Description | F4 "SMD AMPLIFIER 1W" 0 0 50 H I C CNN "Description"
28 | AP4890 | 5 | Comment | F5 "AP4890" 0 0 50 H I C CNN "Comment"
28 | SOP8 | 6 | TYPE | F6 "SOP8" 0 0 50 H I C CNN "TYPE"
28 | APLUS | 7 | MAKER | F7 "APLUS" 0 0 50 H I C CNN "MAKER"
29 | SMD BUFFER | 4 | Description | F4 "SMD BUFFER" 0 0 50 H I C CNN "Description"
29 | ULN2003D1013TR | 5 | Comment | F5 "ULN2003D1013TR" 0 0 50 H I C CNN "Comment"
29 | SOP-16 | 6 | TYPE | F6 "SOP-16" 0 0 50 H I C CNN "TYPE"
29 | STMicroelectronics | 7 | MAKER | F7 "STMicroelectronics" 0 0 50 H I C CNN "MAKER"
30 | SMD DIODE SCHOTTKY | 4 | Description | F4 "SMD DIODE SCHOTTKY" 0 0 50 H I C CNN "Description"
30 | MBRAF3200T3G | 5 | Comment | F5 "MBRAF3200T3G" 0 0 50 H I C CNN "Comment"
30 | SMA | 6 | TYPE | F6 "SMA" 0 0 50 H I C CNN "TYPE"
30 | MDD, ON SEMICONDUCTOR | 7 | MAKER | F7 "MDD, ON SEMICONDUCTOR" 0 0 50 H I C CNN "MAKER"
31 | SMD DIODE TVS | 4 | Description | F4 "SMD DIODE TVS" 0 0 50 H I C CNN "Description"
31 | SMBJ15A | 5 | Comment | F5 "SMBJ15A" 0 0 50 H I C CNN "Comment"
31 | SMB | 6 | TYPE | F6 "SMB" 0 0 50 H I C CNN "TYPE"
31 | SAMYANG ELECTRONICS | 7 | MAKER | F7 "SAMYANG ELECTRONICS" 0 0 50 H I C CNN "MAKER"
32 | SMD ELECT CAPACITOR | 4 | Description | F4 "SMD ELECT CAPACITOR" 0 0 50 H I C CNN "Description"
32 | 220uF/6.3V | 5 | Comment | F5 "220uF/6.3V" 0 0 50 H I C CNN "Comment"
32 | SC 6.3X5.8 | 6 | TYPE | F6 "SC 6.3X5.8" 0 0 50 H I C CNN "TYPE"
32 | SAMYOUNG | 7 | MAKER | F7 "SAMYOUNG" 0 0 50 H I C CNN "MAKER"
33 | SMD INDUCTOR | 4 | Description | F4 "SMD INDUCTOR" 0 0 50 H I C CNN "Description"
33 | SC7850D-221K | 5 | Comment | F5 "SC7850D-221K" 0 0 50 H I C CNN "Comment"
33 | 7850 | 6 | TYPE | F6 "7850" 0 0 50 H I C CNN "TYPE"
33 | SUHKWANG | 7 | MAKER | F7 "SUHKWANG" 0 0 50 H I C CNN "MAKER"
34 | SMD JACK USB C TYPE | 4 | Description | F4 "SMD JACK USB C TYPE" 0 0 50 H I C CNN "Description"
34 | USB-TYPE-C-31-M-17 | 5 | Comment | F5 "USB-TYPE-C-31-M-17" 0 0 50 H I C CNN "Comment"
34 | SMD-6 | 6 | TYPE | F6 "SMD-6" 0 0 50 H I C CNN "TYPE"
34 | Korean-Hroparts-Elec | 7 | MAKER | F7 "Korean-Hroparts-Elec" 0 0 50 H I C CNN "MAKER"
35 | SMD MCU | 4 | Description | F4 "SMD MCU" 0 0 50 H I C CNN "Description"
35 | STM32G070RBT6 | 5 | Comment | F5 "STM32G070RBT6" 0 0 50 H I C CNN "Comment"
35 | LQFP64 | 6 | TYPE | F6 "LQFP64" 0 0 50 H I C CNN "TYPE"
35 | STMicroelectronics | 7 | MAKER | F7 "STMicroelectronics" 0 0 50 H I C CNN "MAKER"
36 | SMD MOSFET N-CHANNEL | 4 | Description | F4 "SMD MOSFET N-CHANNEL" 0 0 50 H I C CNN "Description"
36 | FDT86246L | 5 | Comment | F5 "FDT86246L" 0 0 50 H I C CNN "Comment"
36 | SOT-223 | 6 | TYPE | F6 "SOT-223" 0 0 50 H I C CNN "TYPE"
36 | FAIRCHILD | 7 | MAKER | F7 "FAIRCHILD" 0 0 50 H I C CNN "MAKER"
37 | SMD REGULATOR | 4 | Description | F4 "SMD REGULATOR" 0 0 50 H I C CNN "Description"
37 | LMT117-ADJ | 5 | Comment | F5 "LMT117-ADJ" 0 0 50 H I C CNN "Comment"
37 | SOT-223 | 6 | TYPE | F6 "SOT-223" 0 0 50 H I C CNN "TYPE"
37 | TGS | 7 | MAKER | F7 "TGS" 0 0 50 H I C CNN "MAKER"
38 | SMD SERIAL FLASH | 4 | Description | F4 "SMD SERIAL FLASH" 0 0 50 H I C CNN "Description"
38 | W25Q32JVSSIQ | 5 | Comment | F5 "W25Q32JVSSIQ" 0 0 50 H I C CNN "Comment"
38 | SOIC-8(208mil) | 6 | TYPE | F6 "SOIC-8(208mil)" 0 0 50 H I C CNN "TYPE"
38 | WINBOND | 7 | MAKER | F7 "WINBOND" 0 0 50 H I C CNN "MAKER"
39 | SMD VOICE | 4 | Description | F4 "SMD VOICE" 0 0 50 H I C CNN "Description"
39 | VLN1MM04S8X | 5 | Comment | F5 "VLN1MM04S8X" 0 0 50 H I C CNN "Comment"
39 | SOP-8 | 6 | TYPE | F6 "SOP-8" 0 0 50 H I C CNN "TYPE"
39 | SYNOOS | 7 | MAKER | F7 "SYNOOS" 0 0 50 H I C CNN "MAKER"
40 | SMD WAFER | 4 | Description | F4 "SMD WAFER" 0 0 50 H I C CNN "Description"
40 | 12505WR-02 | 5 | Comment | F5 "12505WR-02" 0 0 50 H I C CNN "Comment"
40 | SMD-2 | 6 | TYPE | F6 "SMD-2" 0 0 50 H I C CNN "TYPE"
40 | YEONHO ELECTRONICS | 7 | MAKER | F7 "YEONHO ELECTRONICS" 0 0 50 H I C CNN "MAKER"
41 | SMD WAFER | 4 | Description | F4 "SMD WAFER" 0 0 50 H I C CNN "Description"
41 | 12505WS-08 | 5 | Comment | F5 "12505WS-08" 0 0 50 H I C CNN "Comment"
41 | SMD-8 | 6 | TYPE | F6 "SMD-8" 0 0 50 H I C CNN "TYPE"
41 | YEONHO ELECTRONICS | 7 | MAKER | F7 "YEONHO ELECTRONICS" 0 0 50 H I C CNN "MAKER"
42 | SMD WAFER | 4 | Description | F4 "SMD WAFER" 0 0 50 H I C CNN "Description"
42 | 12505WS-09 | 5 | Comment | F5 "12505WS-09" 0 0 50 H I C CNN "Comment"
42 | SMD-9 | 6 | TYPE | F6 "SMD-9" 0 0 50 H I C CNN "TYPE"
42 | YEONHO ELECTRONICS | 7 | MAKER | F7 "YEONHO ELECTRONICS" 0 0 50 H I C CNN "MAKER"
43 | SPEAKER | 4 | Description | F4 "SPEAKER" 0 0 50 H I C CNN "Description"
43 | TDM15A-8-L055C0.5S-0.3D | 5 | Comment | F5 "TDM15A-8-L055C0.5S-0.3D" 0 0 50 H I C CNN "Comment"
43 | ASS'Y | 6 | TYPE | F6 "ASS'Y" 0 0 50 H I C CNN "TYPE"
43 | NCEI | 7 | MAKER | F7 "NCEI" 0 0 50 H I C CNN "MAKER"
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

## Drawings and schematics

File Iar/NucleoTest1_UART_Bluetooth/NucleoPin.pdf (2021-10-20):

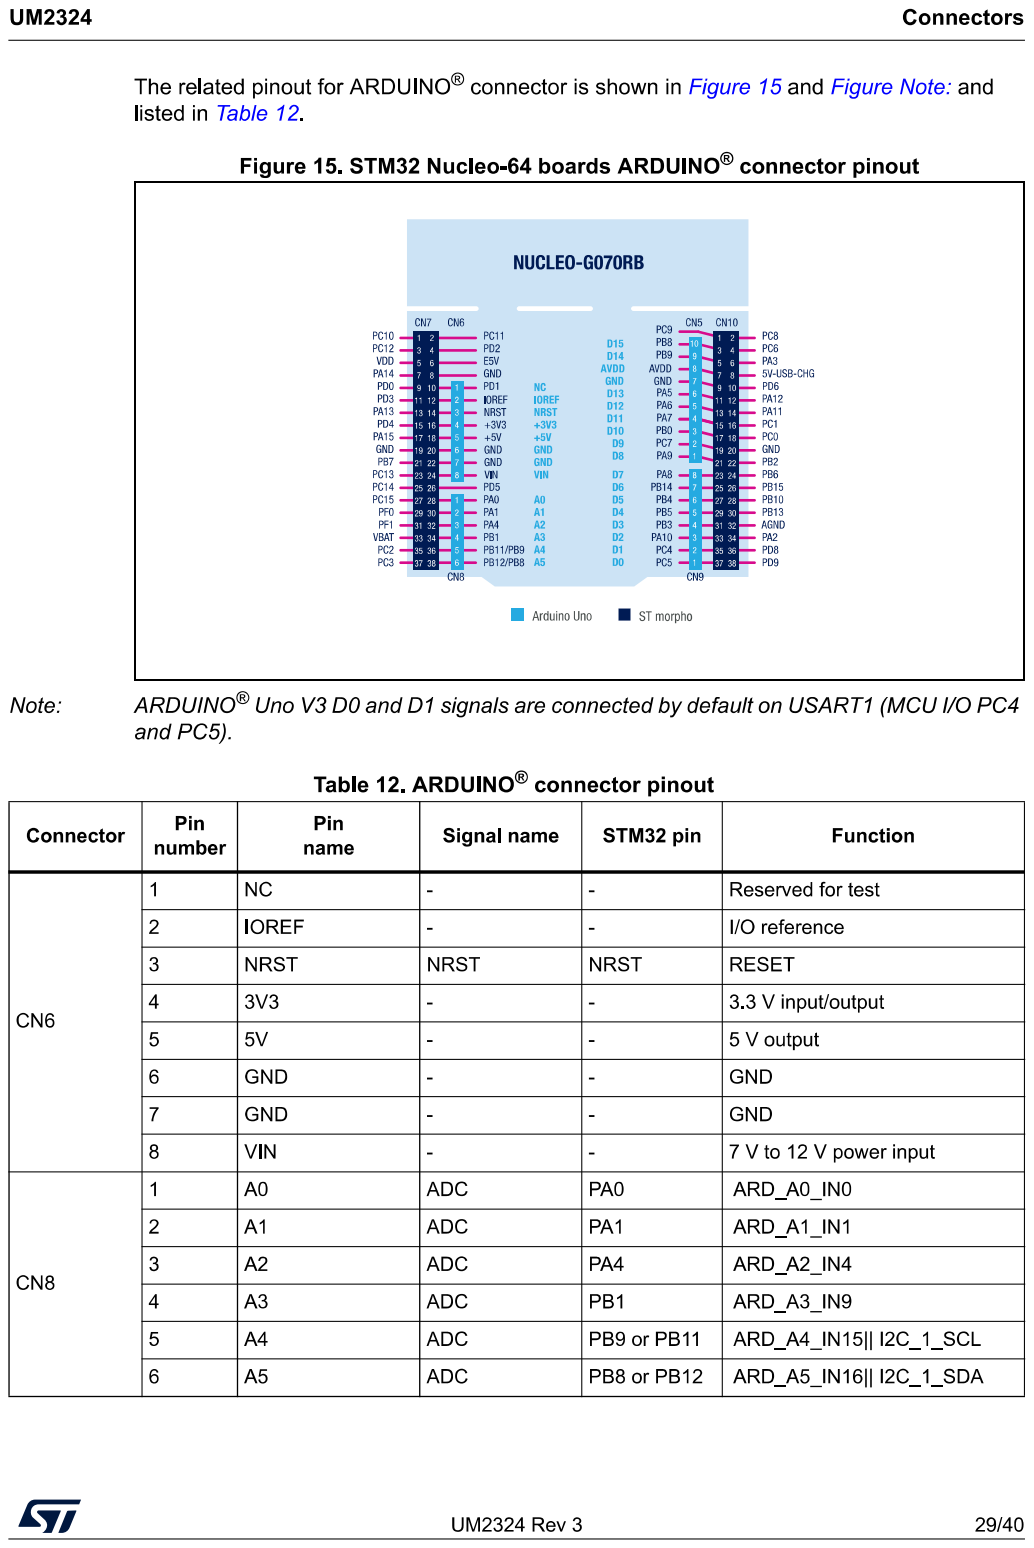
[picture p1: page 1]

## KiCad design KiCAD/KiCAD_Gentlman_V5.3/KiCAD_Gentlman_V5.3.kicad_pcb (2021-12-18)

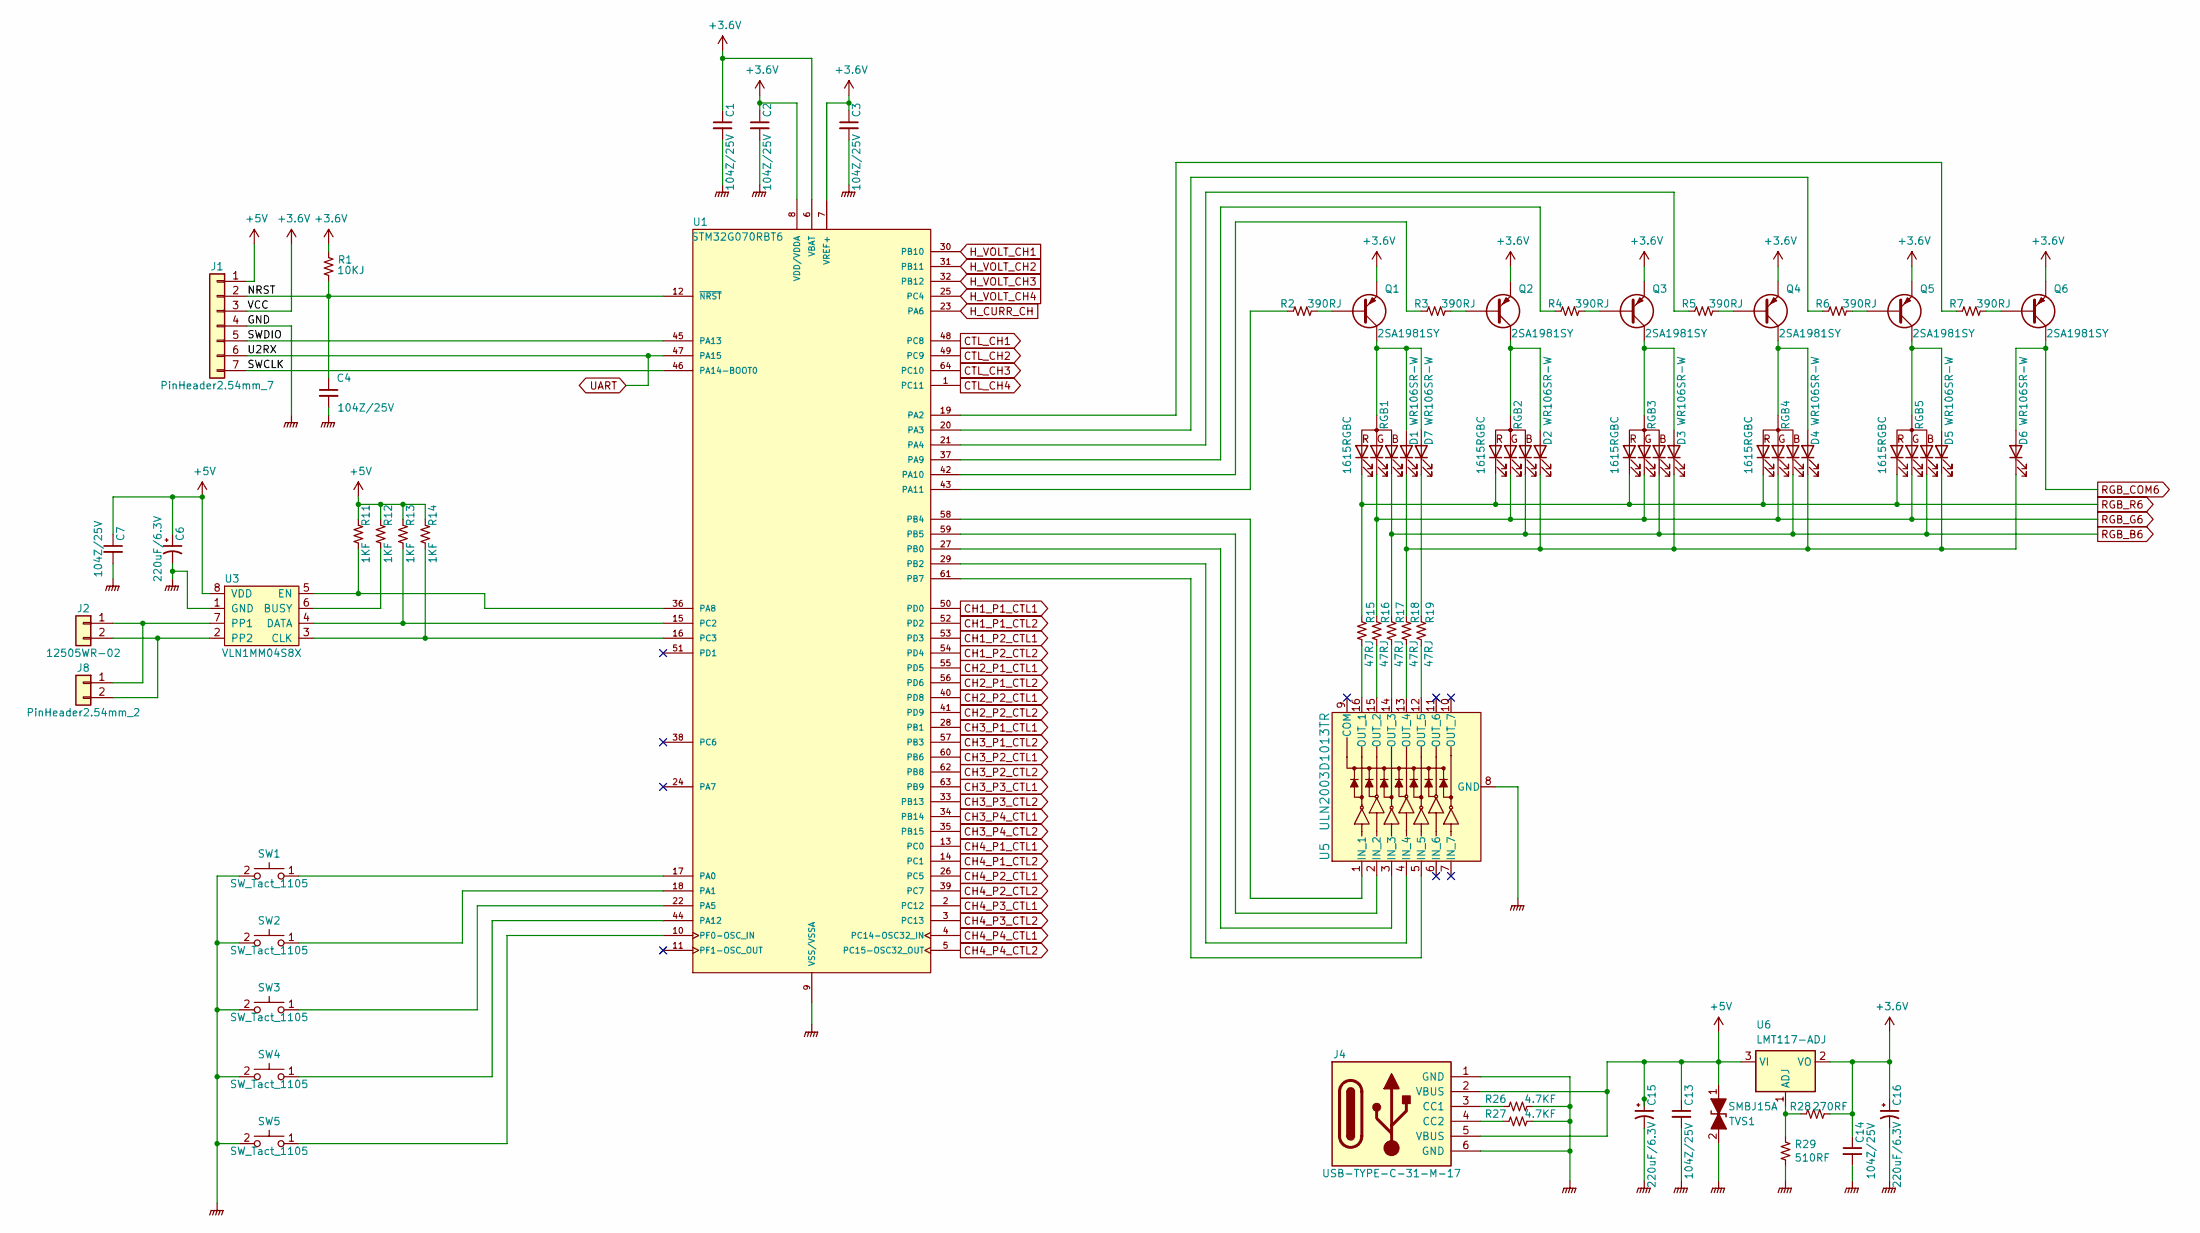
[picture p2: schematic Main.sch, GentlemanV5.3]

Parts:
C1, C2, C3, C4, C7, C13, C14: CAP_104Z_25V_1608; C_0603_1608Metric; PartName 104Z/25V
C6, C15, C16: CAP_220uF_6.3V_SC6.3X5.8; C_Elec_6.3x5.8; PartName 220uF/6.3V
CN1: PinHeader2.54mm_7; PinHeader_1x07_P2.54mm_Vertical; PartName PinHeader2.54mm-7P
CN2: 12505WR-02; PartName 12505WR-02
D1, D2, D3, D4, D5, D6, D7: WR106SR-W; LED_0603_1608Metric; PartName WR106SR-W
J4: USB-TYPE-C-31-M-17; TYPE-C-31-M-17-1; PartName USB-TYPE-C-31-M-17
J8: PinHeader2.54mm_2; PinHeader_1x02_P2.54mm_Vertical; PartName PinHeader2.54mm_2
Q1, Q2, Q3, Q4, Q5, Q6: 2SA1981SY; SOT-23; PartName 2SA1981SY
R1: R_10KJ; R_0603_1608Metric; PartName 10KJ
R2, R3, R4, R5, R6, R7: R_390RJ; R_0603_1608Metric; PartName 390RJ
R11, R12, R13, R14: R_1KF; R_0603_1608Metric; PartName 1KF
R15, R16, R17, R18, R19: R_47RJ; R_0603_1608Metric; PartName 47RJ
R26, R27: R_4.7KF; R_0603_1608Metric; PartName 4.7KF
R28: R_270RF; R_0603_1608Metric; PartName 270RF
R29: R_510RF; R_0603_1608Metric; PartName 510RF
RGB1, RGB2, RGB3, RGB4, RGB5: 1615RGBC; LED_RGB_0605; PartName 1615RGBC
SW1, SW2, SW3, SW4, SW5: SW_Tact_1105; SW_PUSH_6mm_H5mm; PartName ITS-1105-5mm
TVS1: SMBJ15A; D_SMB; PartName SMBJ15A
U1: STM32G070RBT6; LQFP-64_10x10mm_P0.5mm; PartName STM32G070RBT6
U3: VLN1MM04S8X; SOP-8_3.76x4.96mm_P1.27mm; PartName VLN1MM04S8X
U5: ULN2003D1013TR; SOIC-16_3.9x9.9mm_P1.27mm; PartName ULN2003D1013TR
U6: LMT117-ADJ; SOT-223-3_TabPin2; PartName LMT117-ADJ

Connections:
+3.6V: C1.1, C2.1, C3.1, C14.1, C16.1, Q1.2 (E), Q2.2 (E), Q3.2 (E), Q4.2 (E), Q5.2 (E), Q6.2 (E), R1.1, R28.1, U1.6 (VBAT), U1.7 (VREF+), U1.8 (VDD/VDDA), U6.2 (VO); also elsewhere on the board
+5V: C6.1, C7.1, C13.1, C15.1, J4.2 (VBUS), J4.5 (VBUS), R11.1, R12.1, R13.1, R14.1, TVS1.1 (A1), U3.8 (VDD), U6.3 (VI); also elsewhere on the board
/Main/NRST: C4.1, R1.2, U1.12 (~NRST); also elsewhere on the board
/Main/SWCLK: U1.46 (PA14-BOOT0); also elsewhere on the board
/Main/SWDIO: U1.45 (PA13); also elsewhere on the board
CH1_P1_CTL1: U1.50 (PD0); also elsewhere on the board
CH1_P1_CTL2: U1.52 (PD2); also elsewhere on the board
CH1_P2_CTL1: U1.53 (PD3); also elsewhere on the board
CH1_P2_CTL2: U1.54 (PD4); also elsewhere on the board
CH2_P1_CTL1: U1.55 (PD5); also elsewhere on the board
CH2_P1_CTL2: U1.56 (PD6); also elsewhere on the board
CH2_P2_CTL1: U1.40 (PD8); also elsewhere on the board
CH2_P2_CTL2: U1.41 (PD9); also elsewhere on the board
CH3_P1_CTL1: U1.28 (PB1); also elsewhere on the board
CH3_P1_CTL2: U1.57 (PB3); also elsewhere on the board
CH3_P2_CTL1: U1.60 (PB6); also elsewhere on the board
CH3_P2_CTL2: U1.62 (PB8); also elsewhere on the board
CH3_P3_CTL1: U1.63 (PB9); also elsewhere on the board
CH3_P3_CTL2: U1.33 (PB13); also elsewhere on the board
CH3_P4_CTL1: U1.34 (PB14); also elsewhere on the board
CH3_P4_CTL2: U1.35 (PB15); also elsewhere on the board
CH4_P1_CTL1: U1.13 (PC0); also elsewhere on the board
CH4_P1_CTL2: U1.14 (PC1); also elsewhere on the board
CH4_P2_CTL1: U1.26 (PC5); also elsewhere on the board
CH4_P2_CTL2: U1.39 (PC7); also elsewhere on the board
CH4_P3_CTL1: U1.2 (PC12); also elsewhere on the board
CH4_P3_CTL2: U1.3 (PC13); also elsewhere on the board
CH4_P4_CTL1: U1.4 (PC14-OSC32_IN); also elsewhere on the board
CH4_P4_CTL2: U1.5 (PC15-OSC32_OUT); also elsewhere on the board
CTL_CH1: U1.48 (PC8); also elsewhere on the board
CTL_CH2: U1.49 (PC9); also elsewhere on the board
CTL_CH3: U1.64 (PC10); also elsewhere on the board
CTL_CH4: U1.1 (PC11); also elsewhere on the board
GNDPWR: C1.2, C2.2, C3.2, C4.2, C6.2, C7.2, C13.2, C14.2, C15.2, C16.2, J4.1 (GND), J4.6 (GND), R26.1, R27.1, R29.2, SW1.2, SW2.2, SW3.2, SW4.2, SW5.2, TVS1.2 (A2), U1.9 (VSS/VSSA), U3.1 (GND), U5.8 (GND); also elsewhere on the board
H_CURR_CH: U1.23 (PA6); also elsewhere on the board
H_VOLT_CH1: U1.30 (PB10); also elsewhere on the board
H_VOLT_CH2: U1.31 (PB11); also elsewhere on the board
H_VOLT_CH3: U1.32 (PB12); also elsewhere on the board
H_VOLT_CH4: U1.25 (PC4); also elsewhere on the board
unnamed: D1.1 (K), D2.1 (K), D3.1 (K), D4.1 (K), D5.1 (K), D6.1 (K), R18.1
unnamed: D1.2 (A), D7.2 (A), Q1.3 (C), RGB1.4 (A)
unnamed: D2.2 (A), Q2.3 (C), RGB2.4 (A)
unnamed: D3.2 (A), Q3.3 (C), RGB3.4 (A)
unnamed: D4.2 (A), Q4.3 (C), RGB4.4 (A)
unnamed: D5.2 (A), Q5.3 (C), RGB5.4 (A)
unnamed: D7.1 (K), R19.1
unnamed 80: J8.1, U3.7 (PP1); also elsewhere on the board
unnamed 81: J8.2, U3.2 (PP2); also elsewhere on the board
unnamed: J4.3 (CC1), R26.2
unnamed: J4.4 (CC2), R27.2
unnamed: Q1.1 (B), R2.1
unnamed: Q2.1 (B), R3.1
unnamed: Q3.1 (B), R4.1
unnamed: Q4.1 (B), R5.1
unnamed: Q5.1 (B), R6.1
unnamed: Q6.1 (B), R7.1
unnamed: R2.2, U1.43 (PA11)
unnamed: R3.2, U1.42 (PA10)
unnamed: R4.2, U1.37 (PA9)
unnamed: R5.2, U1.21 (PA4)
unnamed: R6.2, U1.20 (PA3)
unnamed: R7.2, U1.19 (PA2)
unnamed: R11.2, U1.36 (PA8), U3.5 (EN)
unnamed: R12.2, U3.6 (BUSY)
unnamed: R13.2, U1.15 (PC2), U3.4 (DATA)
unnamed: R14.2, U1.16 (PC3), U3.3 (CLK)
unnamed: R15.2, U5.16 (OUT_1)
unnamed: R16.2, U5.15 (OUT_2)
unnamed: R17.2, U5.14 (OUT_3)
unnamed: R18.2, U5.13 (OUT_4)
unnamed: R19.2, U5.12 (OUT_5)
unnamed: R28.2, R29.1, U6.1 (ADJ)
unnamed: SW1.1, U1.17 (PA0)
unnamed: SW2.1, U1.18 (PA1)
unnamed: SW3.1, U1.22 (PA5)
unnamed: SW4.1, U1.44 (PA12)
unnamed: SW5.1, U1.10 (PF0-OSC_IN)
unnamed: U1.27 (PB0), U5.3 (IN_3)
unnamed: U1.29 (PB2), U5.4 (IN_4)
unnamed: U1.58 (PB4), U5.1 (IN_1)
unnamed: U1.59 (PB5), U5.2 (IN_2)
unnamed: U1.61 (PB7), U5.5 (IN_5)
RGB_B6: R17.1, RGB1.3 (BK), RGB2.3 (BK), RGB3.3 (BK), RGB4.3 (BK), RGB5.3 (BK); also elsewhere on the board
RGB_COM6: D6.2 (A), Q6.3 (C); also elsewhere on the board
RGB_G6: R16.1, RGB1.2 (GK), RGB2.2 (GK), RGB3.2 (GK), RGB4.2 (GK), RGB5.2 (GK); also elsewhere on the board
RGB_R6: R15.1, RGB1.1 (RK), RGB2.1 (RK), RGB3.1 (RK), RGB4.1 (RK), RGB5.1 (RK); also elsewhere on the board
UART: U1.47 (PA15); also elsewhere on the board

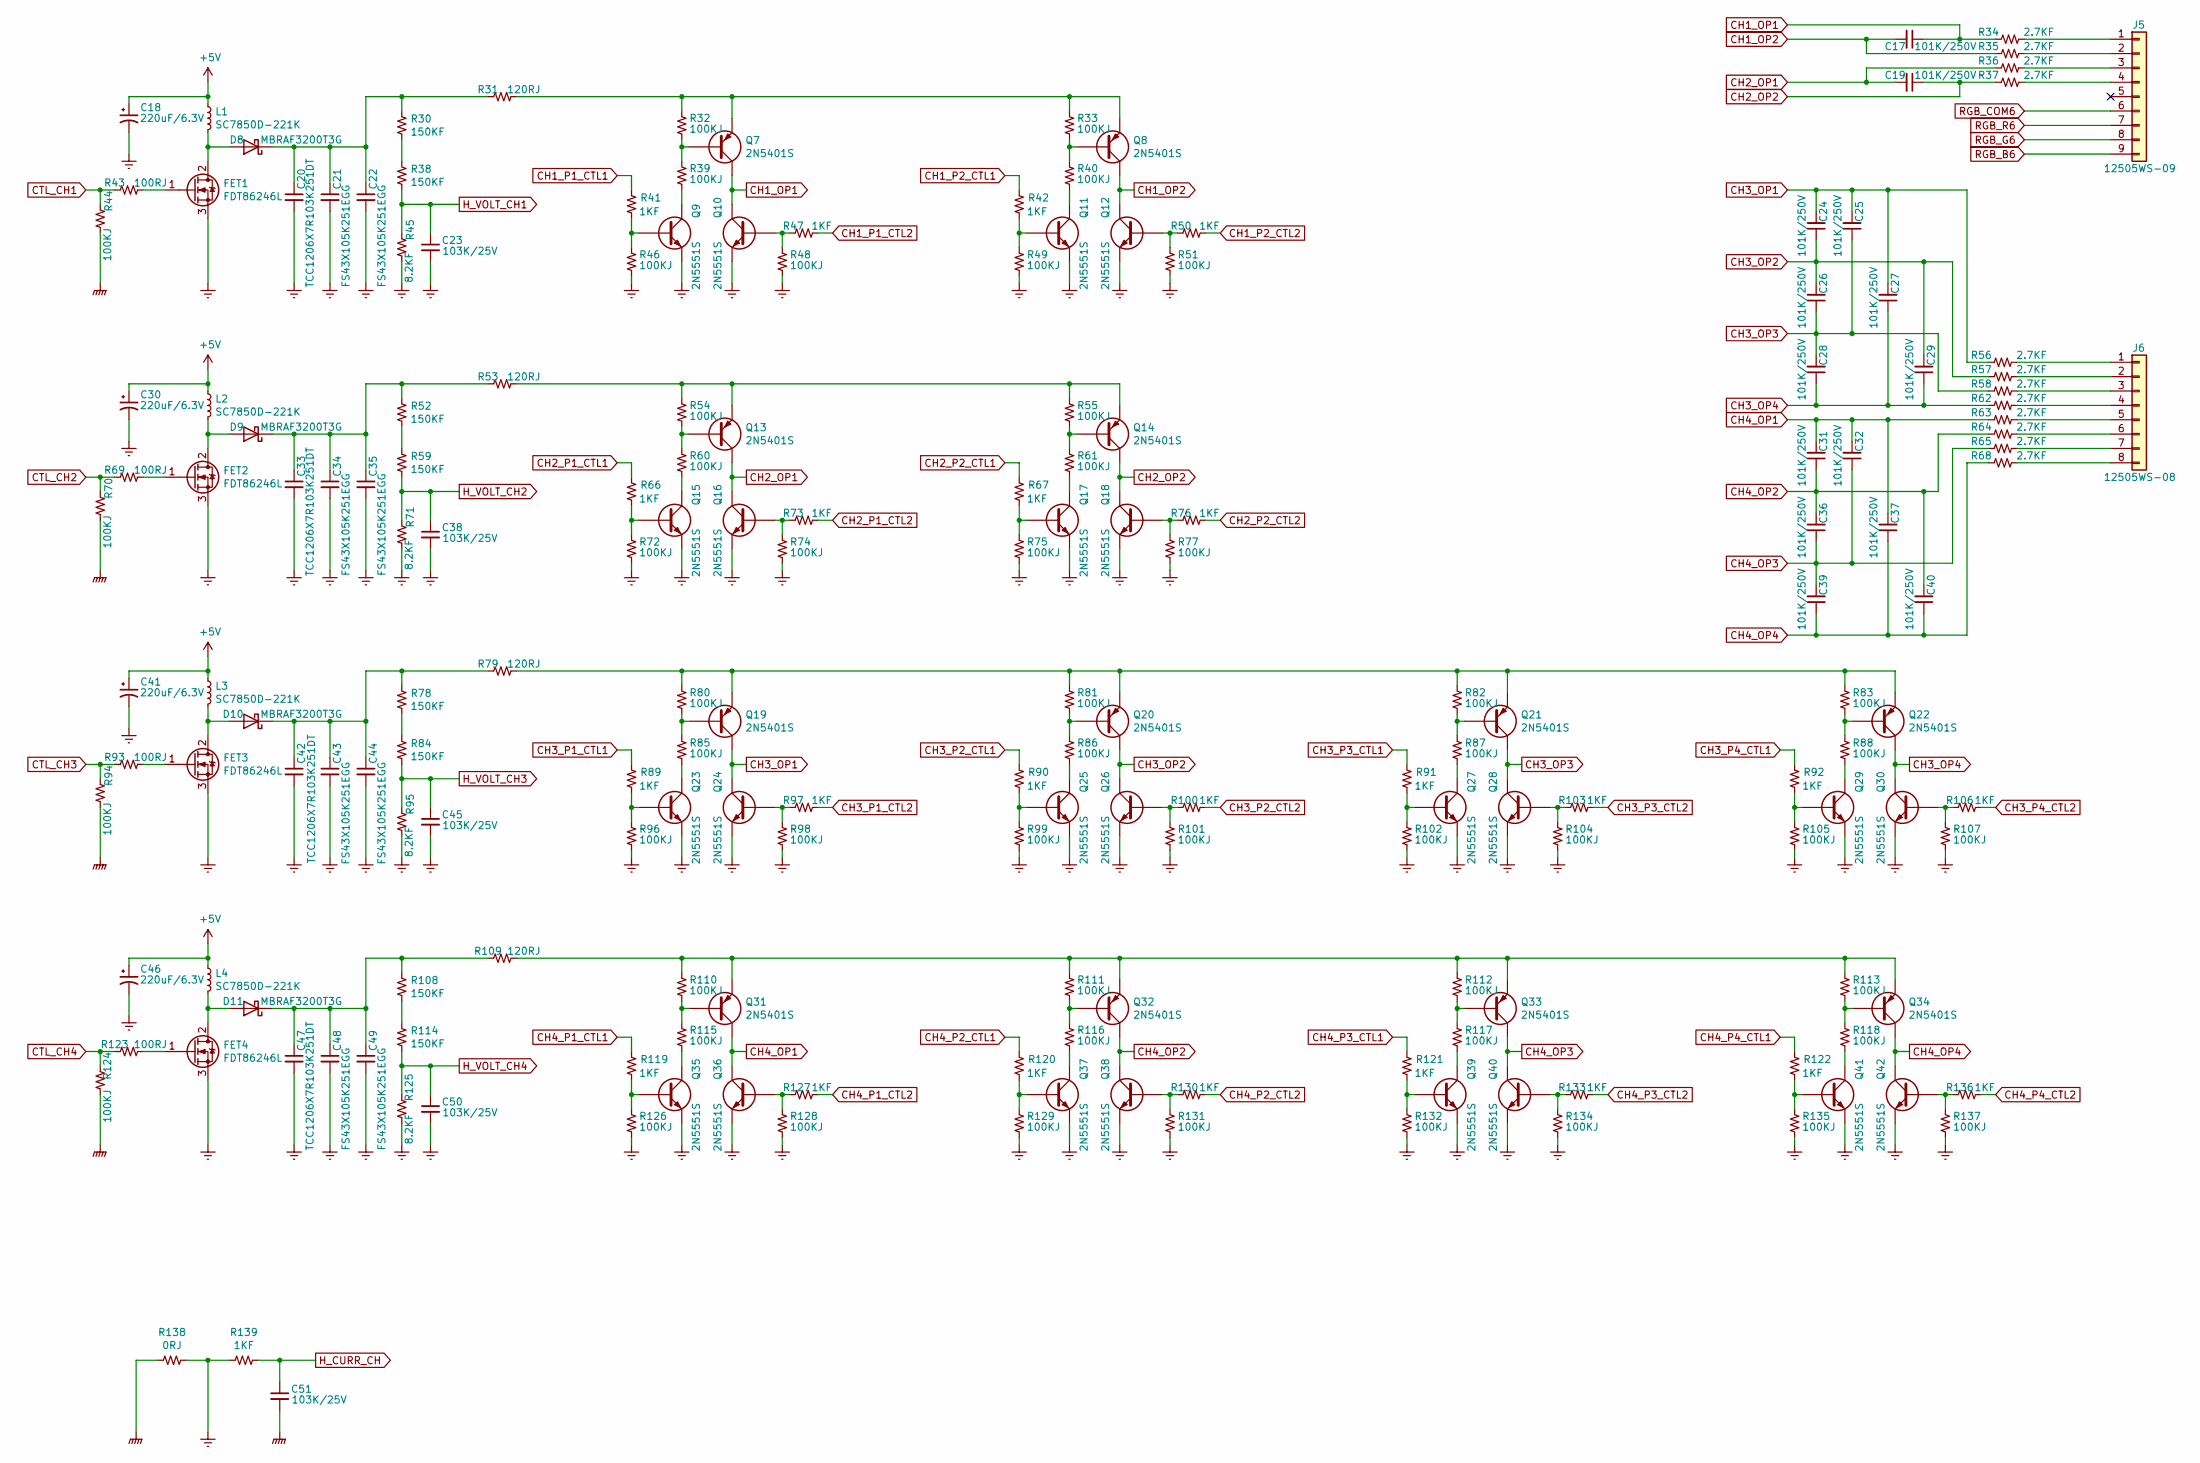
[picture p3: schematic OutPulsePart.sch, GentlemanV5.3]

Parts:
C17, C19, C24, C25, C26, C27, C28, C29, C31, C32, C36, C37, C39, C40: CAP_101K_250V_2012; C_0805_2012Metric; PartName 101K/250V
C18, C30, C41, C46: CAP_220uF_6.3V_SC6.3X5.8; C_Elec_6.3x5.8; PartName 220uF/6.3V
C20, C33, C42, C47: CAP_103K_250V_3216; C_1206_3216Metric; PartName TCC1206X7R103K251DT
C21, C22, C34, C35, C43, C44, C48, C49: CAP_105K_250V_4532; C_1812_4532Metric; PartName FS43X105K251EGG
C23, C38, C45, C50, C51: CAP_103K_25V_1608; C_0603_1608Metric; PartName 103K/25V
D8, D9, D10, D11: MBRAF3200T3G; D_SMA; PartName MBRAF3200T3G
FET1, FET2, FET3, FET4: FDT86246L; SOT-223-3_TabPin2; PartName FDT86246L
J5: 12505WS-09; PartName 12505WS-09
J6: 12505WS-08; PartName 12505WS-08
L1, L2, L3, L4: SC7850D-221K; L_SC7850D-221K; PartName SC7850D-221K
Q7, Q8, Q13, Q14, Q19, Q20, Q21, Q22, Q31, Q32, Q33, Q34: 2N5401S; SOT-23; PartName 2N5401S
Q9, Q10, Q11, Q12, Q15, Q16, Q17, Q18, Q23, Q24, Q25, Q26, Q27, Q28, Q29, Q30, Q35, Q36, Q37, Q38, Q39, Q40, Q41, Q42: 2N5551S; SOT-23; PartName 2N5551S
R30, R38, R52, R59, R78, R84, R108, R114: R_150KF_2012; R_0805_2012Metric; PartName 150KF
R31, R53, R79, R109: R_120RJ_3216; R_1206_3216Metric; PartName 120RJ
R32, R33, R39, R40, R44, R46, R48, R49, R51, R54, R55, R60, R61, R70, R72, R74, R75, R77, R80, R81, R82, R83, R85, R86, R87, R88, R94, R96, R98, R99, R101, R102, R104, R105, R107, R110, R111, R112, R113, R115, R116, R117, R118, R124, R126, R128, R129, R131, R132, R134, R135, R137: R_100KJ; R_0603_1608Metric; PartName 100KJ
R34, R35, R36, R37, R56, R57, R58, R62, R63, R64, R65, R68: R_2.7KF; R_0603_1608Metric; PartName 2.7KF
R41, R42, R47, R50, R66, R67, R73, R76, R89, R90, R91, R92, R97, R100, R103, R106, R119, R120, R121, R122, R127, R130, R133, R136, R139: R_1KF; R_0603_1608Metric; PartName 1KF
R43, R69, R93, R123: R_100RJ; R_0603_1608Metric; PartName 100RJ
R45, R71, R95, R125: R_8.2KF; R_0603_1608Metric; PartName 8.2KF
R138: R_0RJ_6432; R_3522_6432Metric; PartName 0RJ

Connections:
+5V: C18.1, C30.1, C41.1, C46.1, L1.1, L2.1, L3.1, L4.1; also elsewhere on the board
CH1_OP1: C17.1, Q7.3 (C), Q10.3 (C), R34.2
CH1_OP2: C17.2, Q8.3 (C), Q12.3 (C), R35.2
CH1_P1_CTL1: R41.1; also elsewhere on the board
CH1_P1_CTL2: R47.1; also elsewhere on the board
CH1_P2_CTL1: R42.1; also elsewhere on the board
CH1_P2_CTL2: R50.1; also elsewhere on the board
CH2_OP1: C19.2, Q13.3 (C), Q16.3 (C), R36.2
CH2_OP2: C19.1, Q14.3 (C), Q18.3 (C), R37.2
CH2_P1_CTL1: R66.1; also elsewhere on the board
CH2_P1_CTL2: R73.1; also elsewhere on the board
CH2_P2_CTL1: R67.1; also elsewhere on the board
CH2_P2_CTL2: R76.1; also elsewhere on the board
CH3_OP1: C24.2, C25.2, C27.2, Q19.3 (C), Q24.3 (C), R56.2
CH3_OP2: C24.1, C26.2, C29.2, Q20.3 (C), Q26.3 (C), R57.2
CH3_OP3: C25.1, C26.1, C28.2, Q21.3 (C), Q28.3 (C), R58.2
CH3_OP4: C27.1, C28.1, C29.1, Q22.3 (C), Q30.3 (C), R62.2
CH3_P1_CTL1: R89.1; also elsewhere on the board
CH3_P1_CTL2: R97.1; also elsewhere on the board
CH3_P2_CTL1: R90.1; also elsewhere on the board
CH3_P2_CTL2: R100.1; also elsewhere on the board
CH3_P3_CTL1: R91.1; also elsewhere on the board
CH3_P3_CTL2: R103.1; also elsewhere on the board
CH3_P4_CTL1: R92.1; also elsewhere on the board
CH3_P4_CTL2: R106.1; also elsewhere on the board
CH4_OP1: C31.2, C32.2, C37.2, Q31.3 (C), Q36.3 (C), R63.2
CH4_OP2: C31.1, C36.2, C40.2, Q32.3 (C), Q38.3 (C), R64.2
CH4_OP3: C32.1, C36.1, C39.2, Q33.3 (C), Q40.3 (C), R65.2
CH4_OP4: C37.1, C39.1, C40.1, Q34.3 (C), Q42.3 (C), R68.2
CH4_P1_CTL1: R119.1; also elsewhere on the board
CH4_P1_CTL2: R127.1; also elsewhere on the board
CH4_P2_CTL1: R120.1; also elsewhere on the board
CH4_P2_CTL2: R130.1; also elsewhere on the board
CH4_P3_CTL1: R121.1; also elsewhere on the board
CH4_P3_CTL2: R133.1; also elsewhere on the board
CH4_P4_CTL1: R122.1; also elsewhere on the board
CH4_P4_CTL2: R136.1; also elsewhere on the board
CTL_CH1: R43.2, R44.1; also elsewhere on the board
CTL_CH2: R69.2, R70.1; also elsewhere on the board
CTL_CH3: R93.2, R94.1; also elsewhere on the board
CTL_CH4: R123.2, R124.1; also elsewhere on the board
GNDPWR: C51.2, R44.2, R70.2, R94.2, R124.2, R138.2; also elsewhere on the board
GNDREF: C18.2, C20.2, C21.2, C22.2, C23.2, C30.2, C33.2, C34.2, C35.2, C38.2, C41.2, C42.2, C43.2, C44.2, C45.2, C46.2, C47.2, C48.2, C49.2, C50.2, FET1.3 (S), FET2.3 (S), FET3.3 (S), FET4.3 (S), Q9.2 (E), Q10.2 (E), Q11.2 (E), Q12.2 (E), Q15.2 (E), Q16.2 (E), Q17.2 (E), Q18.2 (E), Q23.2 (E), Q24.2 (E), Q25.2 (E), Q26.2 (E), Q27.2 (E), Q28.2 (E), Q29.2 (E), Q30.2 (E), Q35.2 (E), Q36.2 (E), Q37.2 (E), Q38.2 (E), Q39.2 (E), Q40.2 (E), Q41.2 (E), Q42.2 (E), R45.2, R46.2, R48.2, R49.2, R51.2, R71.2, R72.2, R74.2, R75.2, R77.2, R95.2, R96.2, R98.2, R99.2, R101.2, R102.2, R104.2, R105.2, R107.2, R125.2, R126.2, R128.2, R129.2, R131.2, R132.2, R134.2, R135.2, R137.2, R138.1, R139.2
H_CURR_CH: C51.1, R139.1; also elsewhere on the board
H_VOLT_CH1: C23.1, R38.2, R45.1; also elsewhere on the board
H_VOLT_CH2: C38.1, R59.2, R71.1; also elsewhere on the board
H_VOLT_CH3: C45.1, R84.2, R95.1; also elsewhere on the board
H_VOLT_CH4: C50.1, R114.2, R125.1; also elsewhere on the board
unnamed: C20.1, C21.1, C22.1, D8.1 (K), R30.1, R31.2
unnamed: C33.1, C34.1, C35.1, D9.1 (K), R52.1, R53.2
unnamed: C42.1, C43.1, C44.1, D10.1 (K), R78.1, R79.2
unnamed: C47.1, C48.1, C49.1, D11.1 (K), R108.1, R109.2
unnamed: D8.2 (A), FET1.2 (D), L1.2
unnamed: D9.2 (A), FET2.2 (D), L2.2
unnamed: D10.2 (A), FET3.2 (D), L3.2
unnamed: D11.2 (A), FET4.2 (D), L4.2
unnamed: FET1.1 (G), R43.1
unnamed: FET2.1 (G), R69.1
unnamed: FET3.1 (G), R93.1
unnamed: FET4.1 (G), R123.1
unnamed: J5.1, R34.1
unnamed: J5.2, R35.1
unnamed: J5.3, R36.1
unnamed: J5.4, R37.1
unnamed: J6.1, R56.1
unnamed: J6.2, R57.1
unnamed: J6.3, R58.1
unnamed: J6.4, R62.1
unnamed: J6.5, R63.1
unnamed: J6.6, R64.1
unnamed: J6.7, R65.1
unnamed: J6.8, R68.1
unnamed: Q7.1 (B), R32.2, R39.1
unnamed: Q7.2 (E), Q8.2 (E), R31.1, R32.1, R33.1
unnamed: Q8.1 (B), R33.2, R40.1
unnamed: Q9.1 (B), R41.2, R46.1
unnamed: Q9.3 (C), R39.2
unnamed: Q10.1 (B), R47.2, R48.1
unnamed: Q11.1 (B), R42.2, R49.1
unnamed: Q11.3 (C), R40.2
unnamed: Q12.1 (B), R50.2, R51.1
unnamed: Q13.1 (B), R54.2, R60.1
unnamed: Q13.2 (E), Q14.2 (E), R53.1, R54.1, R55.1
unnamed: Q14.1 (B), R55.2, R61.1
unnamed: Q15.1 (B), R66.2, R72.1
unnamed: Q15.3 (C), R60.2
unnamed: Q16.1 (B), R73.2, R74.1
unnamed: Q17.1 (B), R67.2, R75.1
unnamed: Q17.3 (C), R61.2
unnamed: Q18.1 (B), R76.2, R77.1
unnamed: Q19.1 (B), R80.2, R85.1
unnamed: Q19.2 (E), Q20.2 (E), Q21.2 (E), Q22.2 (E), R79.1, R80.1, R81.1, R82.1, R83.1
unnamed: Q20.1 (B), R81.2, R86.1
unnamed: Q21.1 (B), R82.2, R87.1
unnamed: Q22.1 (B), R83.2, R88.1
unnamed: Q23.1 (B), R89.2, R96.1
unnamed: Q23.3 (C), R85.2
unnamed: Q24.1 (B), R97.2, R98.1
unnamed: Q25.1 (B), R90.2, R99.1
unnamed: Q25.3 (C), R86.2
unnamed: Q26.1 (B), R100.2, R101.1
unnamed: Q27.1 (B), R91.2, R102.1
unnamed: Q27.3 (C), R87.2
unnamed: Q28.1 (B), R103.2, R104.1
unnamed: Q29.1 (B), R92.2, R105.1
unnamed: Q29.3 (C), R88.2
unnamed: Q30.1 (B), R106.2, R107.1
unnamed: Q31.1 (B), R110.2, R115.1
unnamed: Q31.2 (E), Q32.2 (E), Q33.2 (E), Q34.2 (E), R109.1, R110.1, R111.1, R112.1, R113.1
unnamed: Q32.1 (B), R111.2, R116.1
unnamed: Q33.1 (B), R112.2, R117.1
unnamed: Q34.1 (B), R113.2, R118.1
unnamed: Q35.1 (B), R119.2, R126.1
unnamed: Q35.3 (C), R115.2
unnamed: Q36.1 (B), R127.2, R128.1
unnamed: Q37.1 (B), R120.2, R129.1
unnamed: Q37.3 (C), R116.2
unnamed: Q38.1 (B), R130.2, R131.1
unnamed: Q39.1 (B), R121.2, R132.1
unnamed: Q39.3 (C), R117.2
unnamed: Q40.1 (B), R133.2, R134.1
unnamed: Q41.1 (B), R122.2, R135.1
unnamed: Q41.3 (C), R118.2
unnamed: Q42.1 (B), R136.2, R137.1
unnamed: R30.2, R38.1
unnamed: R52.2, R59.1
unnamed: R78.2, R84.1
unnamed: R108.2, R114.1
RGB_B6: J5.9; also elsewhere on the board
RGB_COM6: J5.6; also elsewhere on the board
RGB_G6: J5.8; also elsewhere on the board
RGB_R6: J5.7; also elsewhere on the board

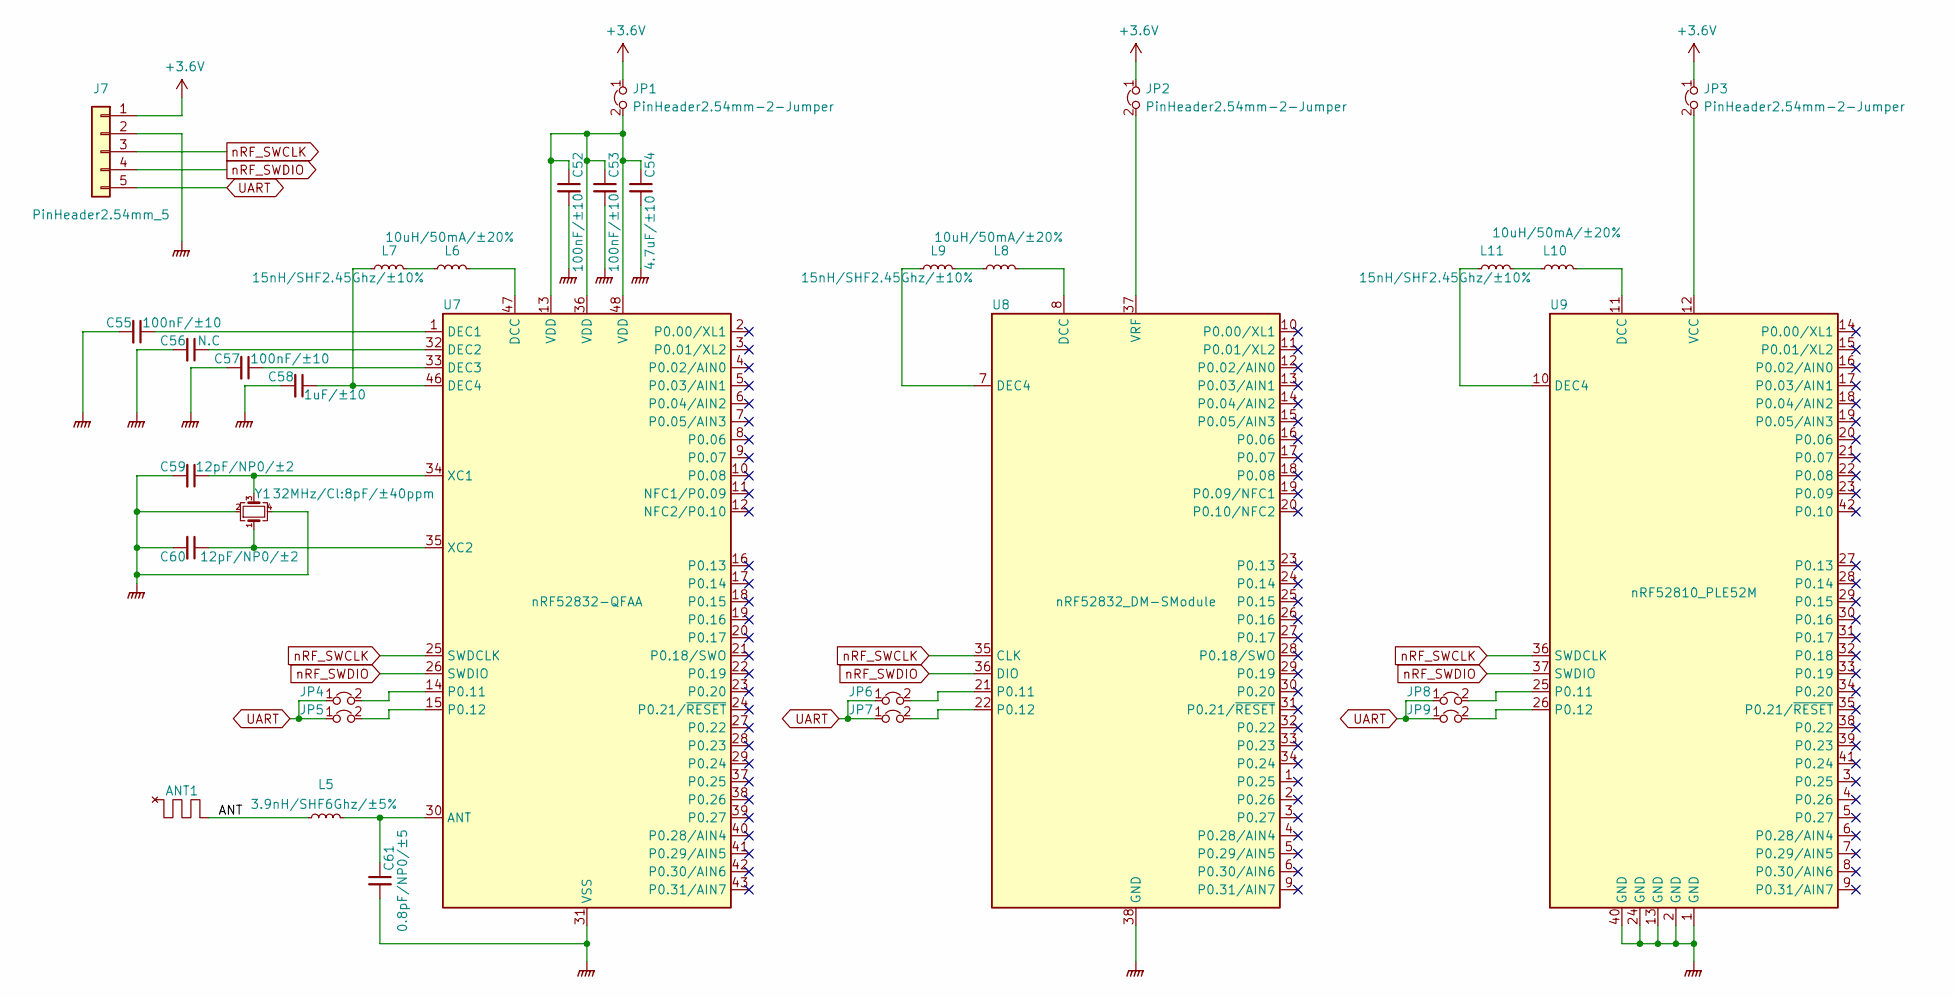
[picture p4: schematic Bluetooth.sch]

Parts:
ANT1: ANT; ANT_PATTERN
C52, C53, C55, C57: CAP_100nF_1005; C_0402_1005Metric; PartName 100nF/±10
C54: CAP_4.7uF_1005; C_0402_1005Metric; PartName 4.7uF/±10
C56: CAP_N.C_1005; C_0402_1005Metric; PartName N.C
C58: CAP_1uF_1005; C_0402_1005Metric; PartName 1uF/±10
C59, C60: CAP_12pF_1005; C_0402_1005Metric; PartName 12pF/NP0/±2
C61: CAP_0.8pF_1005; C_0402_1005Metric; PartName 0.8pF/NP0/±5
J7: PinHeader2.54mm_5; PinHeader_1x05_P2.54mm_Vertical; PartName PinHeader2.54mm-5P
JP1, JP2, JP3, JP4, JP5, JP6, JP7, JP8, JP9: PinHeader2.54mm-2-Jumper; PinHeader_1x02_P2.54mm_Vertical; PartName PinHeader2.54mm-2-Jumper
L5: L_3.9nH; L_0402_1005Metric; PartName 3.9nH/SHF6Ghz/±5%
L6, L8, L10: L_10uH; L_0603_1608Metric; PartName 10uH/50mA/±20%
L7, L9, L11: L_15nH; L_0402_1005Metric; PartName 15nH/SHF2.45Ghz/±10%
U7: nRF52832-QFAA; QFN-48-1EP_6x6mm_P0.4mm_EP4.3x4.3mm; PartName nRF52832-QFAA
U8: nRF52832_DM-SModule; PartName nRF52832_DM-SModule
U9: nRF52810_PLE52M; PartName nRF52810_PLE52M
Y1: Y_32MHz; Crystal_SMD_2016-4Pin_2.0x1.6mm; PartName 32MHz/Cl:8pF/±40ppm

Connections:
+3.6V: J7.1, JP1.1, JP2.1, JP3.1; also elsewhere on the board
/Bluetooth/ANT: ANT1.1, L5.1
GNDPWR: C52.2, C53.2, C54.2, C55.2, C56.2, C57.2, C58.2, C59.2, C60.2, C61.2, J7.2, U7.31 (VSS), U7.45 (VSS), U7.49 (VSS), U8.38 (GND), U9.1 (GND), U9.2 (GND), U9.13 (GND), U9.24 (GND), U9.40 (GND), Y1.2, Y1.4; also elsewhere on the board
unnamed: C52.1, C53.1, C54.1, JP1.2, U7.13 (VDD), U7.36 (VDD), U7.48 (VDD)
unnamed: C55.1, U7.1 (DEC1)
unnamed: C56.1, U7.32 (DEC2)
unnamed: C57.1, U7.33 (DEC3)
unnamed: C58.1, L7.1, U7.46 (DEC4)
unnamed: C59.1, U7.34 (XC1), Y1.3
unnamed: C60.1, U7.35 (XC2), Y1.1
unnamed: C61.1, L5.2, U7.30 (ANT)
unnamed: JP2.2, U8.37 (VRF)
unnamed: JP3.2, U9.12 (VCC)
unnamed: JP4.2, U7.14 (P0.11)
unnamed: JP5.2, U7.15 (P0.12)
unnamed: JP6.2, U8.21 (P0.11)
unnamed: JP7.2, U8.22 (P0.12)
unnamed: JP8.2, U9.25 (P0.11)
unnamed: JP9.2, U9.26 (P0.12)
unnamed: L6.1, L7.2
unnamed: L6.2, U7.47 (DCC)
unnamed: L8.1, L9.2
unnamed: L8.2, U8.8 (DCC)
unnamed: L9.1, U8.7 (DEC4)
unnamed: L10.1, L11.2
unnamed: L10.2, U9.11 (DCC)
unnamed: L11.1, U9.10 (DEC4)
UART: J7.5, JP4.1, JP5.1, JP6.1, JP7.1, JP8.1, JP9.1; also elsewhere on the board
nRF_SWCLK: J7.3, U7.25 (SWDCLK), U8.35 (CLK), U9.36 (SWDCLK)
nRF_SWDIO: J7.4, U7.26 (SWDIO), U8.36 (DIO), U9.37 (SWDIO)

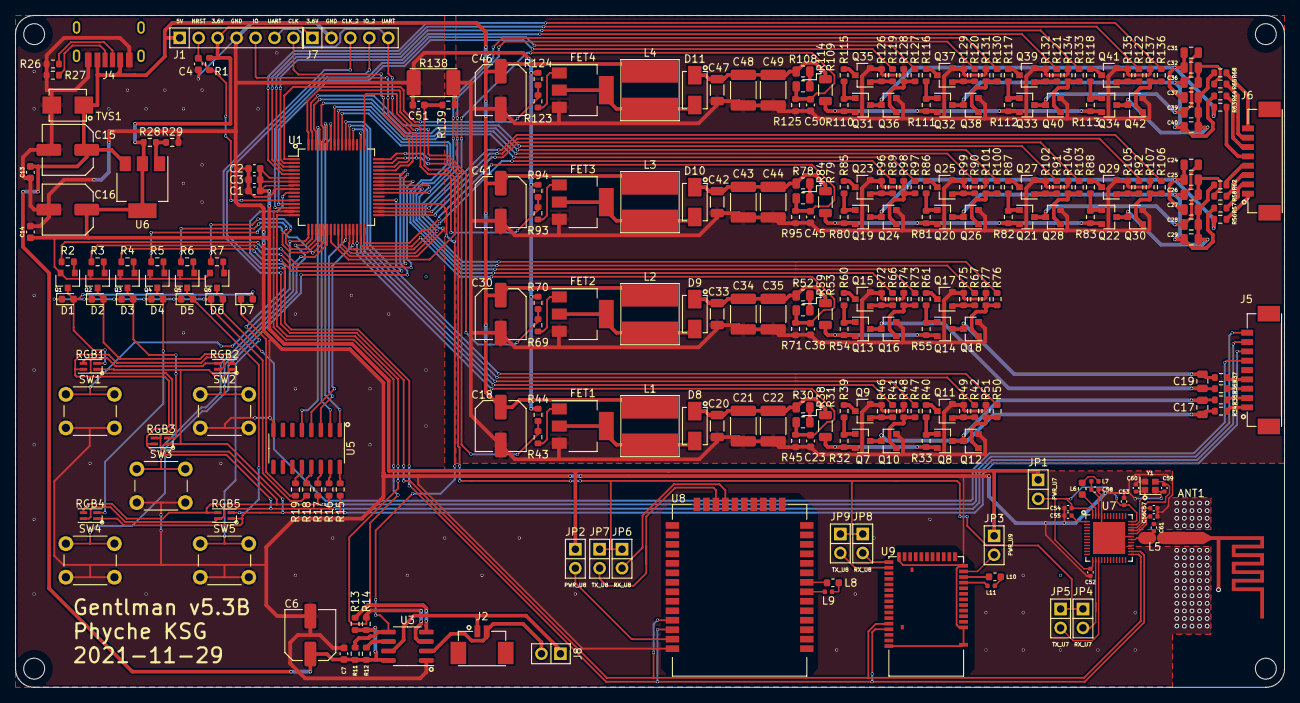
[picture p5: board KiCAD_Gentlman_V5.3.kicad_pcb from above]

Board: 2 copper layers, 170.0 x 90.0 mm, 289 parts (0 on the bottom side), 207 nets.

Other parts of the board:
J1: PinHeader2.54mm_7; PinHeader_1x07_P2.54mm_Vertical
J2: 12505WR-02

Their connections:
+3.6V: J1.3; also elsewhere on the board
+5V: J1.1; also elsewhere on the board
/Main/NRST: J1.2; also elsewhere on the board
/Main/SWCLK: J1.7; also elsewhere on the board
/Main/SWDIO: J1.5; also elsewhere on the board
GNDPWR: J1.4; also elsewhere on the board
unnamed 80: J2.1; also elsewhere on the board
unnamed 81: J2.2; also elsewhere on the board
UART: J1.6; also elsewhere on the board

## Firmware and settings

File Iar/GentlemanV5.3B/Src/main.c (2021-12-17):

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

/* Includes ------------------------------------------------------------------*/
#include "main.h"

/* USER CODE BEGIN Includes */
#include "led_controller.h"
#include "sound_proc.h"
#include "wave_proc.h"
#include "key_proc.h"

/* USER CODE END Includes */

ADC_HandleTypeDef hadc1;
DMA_HandleTypeDef hdma_adc1;

TIM_HandleTypeDef htim1;
TIM_HandleTypeDef htim3;
TIM_HandleTypeDef htim6;

/* USER CODE BEGIN PV */

//Time_Checker value
uint8_t TimChec_50us = 0;			//50usec도달 확인
uint8_t TimChec_100us = 0;			//100usec도달 확인
uint8_t TimChec_100usCnt = 0;		//Tim3반복 횟수(100usec용)
uint8_t TimChec_1ms = 0;			//1msec도달 확인
uint8_t TimChec_1msCnt = 0;			//Tim3반복 횟수(1msec용)
uint8_t TimChec_10ms = 0;			//10msec도달 확인
uint8_t TimChec_10msCnt = 0;		//Tim3반복 횟수(10msec용)
uint8_t TimChec_500ms = 0;			//500msec도달 확인
uint8_t TimChec_500msCnt = 0;		//Tim3반복 횟수(500msec용)
uint8_t TimChec_1s = 0;				//1sec도달 확인
uint8_t TimChec_1sCnt = 0;			//Tim3반복 횟수(1sec용)

//Test
uint8_t tmpBuff[128] = { 0, };

/* USER CODE END PV */

void SystemClock_Config(void);
static void MX_GPIO_Init(void);
static void MX_DMA_Init(void);
static void MX_ADC1_Init(void);
static void MX_TIM1_Init(void);
static void MX_TIM3_Init(void);
static void MX_TIM6_Init(void);
/**
  * @brief  The application entry point.
  * @retval int
  */
int main(void)
{
  /* MCU Configuration--------------------------------------------------------*/

  /* Reset of all peripherals, Initializes the Flash interface and the Systick. */
  HAL_Init();

  /* Configure the system clock */
  SystemClock_Config();

  /* Initialize all configured peripherals */
  MX_GPIO_Init();
  MX_DMA_Init();
  MX_ADC1_Init();
  MX_TIM1_Init();
  MX_TIM3_Init();
  MX_TIM6_Init();
  /* USER CODE BEGIN 2 */

  // Sound 초기화
  {
	  // SoudPlay를 위한 대기시간
	  HAL_Delay(1000);
	  sound_proc_Init();
  }
  
  // Wave 초기화
  {
	  wave_proc_Init(&hadc1, &hdma_adc1, &htim1);
  }

  // Tim3 프로세스 시작
  if (HAL_TIM_Base_Start_IT(&htim3) != HAL_OK)
  {
	  Error_Handler();
  }

  

  /* USER CODE END 2 */

  /* Infinite loop */
  /* USER CODE BEGIN WHILE */
  while (1)
  {
	  if (!TimChec_50us)continue;	// 50us
	  TimChec_50us = 0;

	  {
		  wave_proc_update_main();
	  }

	  if (!TimChec_100us)continue;	// 100us
	  TimChec_100us = 0;

	  // Sound Update
	  {
		  sound_proc_Update();
	  }

	  if (!TimChec_1ms)continue;	// 1ms
	  TimChec_1ms = 0;

	  {
		  wave_proc_update_PatternNode();
	  }

	  if (!TimChec_10ms)continue;	// 10ms
	  TimChec_10ms = 0;

	  // Key Update
	  {
		  key_proc_Update();
	  }

	  // LED Update
	  {
		  led_BlinkColUpdate();
	  }


	  if (!TimChec_500ms)continue;	// 500ms
	  TimChec_500ms = 0;


	  if (!TimChec_1s)continue;	// 1s
	  TimChec_1s = 0;

	  // Optional System Update
	  {
		  wave_proc_update_OptionSys();
	  }

    /* USER CODE END WHILE */

    /* USER CODE BEGIN 3 */
  }
  /* USER CODE END 3 */
}

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
/* USER CODE BEGIN 4 */
void TimeChec_Update(void)
{
	//Main()의 While에 사용될 타이머를 담당한다.
	//Tim3를 이용해 50usec주기로 호출된다.

	//50usec 업데이트
	//if (TimChec_50us == 0xFF) { TimChec_50us == 0x00; }	//예외처리 생략
	++TimChec_50us;

	//100usec 업데이트
	++TimChec_100usCnt;
	if (TimChec_100usCnt > 1)	// 100usec / 50usec - 1
	{
		TimChec_100usCnt = 0;
		//if (TimChec_100usCnt == 0xFF) { TimChec_100usCnt == 0x00; }	//예외처리 생략
		++TimChec_100us;

		//1msec 업데이트
		++TimChec_1msCnt;
		if (TimChec_1msCnt > 9)	// 1msec / 100usec - 1
		{
			TimChec_1msCnt = 0;
			//if (TimChec_1ms == 0xFF) { TimChec_1ms == 0x00; }	//예외처리 생략
			++TimChec_1ms;

			//10msec 업데이트
			++TimChec_10msCnt;
			if (TimChec_10msCnt > 9)	// 10msec / 1msec - 1
			{
				TimChec_10msCnt = 0;
				//if (TimChec_10ms == 0xFF) { TimChec_10ms == 0x00; }	//예외처리 생략
				++TimChec_10ms;

				//500msec 업데이트
				++TimChec_500msCnt;
				if (TimChec_500msCnt > 49)	// 500msec / 10msec - 1
				{
					TimChec_500msCnt = 0;
					//if (TimChec_500ms == 0xFF) { TimChec_500ms == 0x00; }	//예외처리 생략
					++TimChec_500ms;

					++TimChec_1sCnt;
					if (TimChec_1sCnt > 1)	// 1sec / 500msec - 1
					{
						TimChec_1sCnt = 0;
						//if (TimChec_1s == 0xFF) { TimChec_1s == 0x00; }	//예외처리 생략
						++TimChec_1s;
					}
				}
			}
		}
	}

}

/* USER CODE END 4 */
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


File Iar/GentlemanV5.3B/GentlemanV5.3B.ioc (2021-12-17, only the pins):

Mcu.UserName=STM32G070RBTx
PA0.GPIO_Label=SW1
PA0.Signal=GPIO_Input
PA1.GPIO_Label=SW2
PA1.Signal=GPIO_Input
PA10.GPIO_Label=LED_TR2
PA10.Signal=GPIO_Output
PA13.Signal=SYS_SWDIO
PA14-BOOT0.Signal=SYS_SWCLK
PA15.GPIO_Label=UART2
PA15.Signal=USART2_RX
PA2.GPIO_Label=LED_TR6
PA2.Signal=GPIO_Output
PA3.GPIO_Label=LED_TR5
PA3.Signal=GPIO_Output
PA4.GPIO_Label=LED_TR4
PA4.Signal=GPIO_Output
PA5.GPIO_Label=SW3
PA5.Signal=GPIO_Input
PA6.GPIO_Label=ADC_CURR
PA6.Signal=ADC1_IN6
PA7.GPIO_Label=SOUND2_IN
PA7.Signal=GPIO_Output
PA8.GPIO_Label=SOUND1_EN
PA8.Signal=GPIO_Output
PA9.GPIO_Label=LED_TR3
PA9.Signal=GPIO_Output
PB0.GPIO_Label=LED_DTR3
PB0.Signal=GPIO_Output
PB1.GPIO_Label=CH3_1_1
PB1.Signal=GPIO_Output
PB10.GPIO_Label=ADC_CH1
PB10.Signal=ADC1_IN11
PB11.GPIO_Label=ADC_CH2
PB11.Signal=ADC1_IN15
PB12.GPIO_Label=ADC_CH3
PB12.Signal=ADC1_IN16
PB13.GPIO_Label=CH3_3_2
PB13.Signal=GPIO_Output
PB14.GPIO_Label=CH3_4_1
PB14.Signal=GPIO_Output
PB15.GPIO_Label=CH3_4_2
PB15.Signal=GPIO_Output
PB2.GPIO_Label=LED_DTR4
PB2.Signal=GPIO_Output
PB3.GPIO_Label=CH3_1_2
PB3.Signal=GPIO_Output
PB4.GPIO_Label=LED_DTR1
PB4.Signal=GPIO_Output
PB5.GPIO_Label=LED_DTR2
PB5.Signal=GPIO_Output
PB6.GPIO_Label=CH3_2_1
PB6.Signal=GPIO_Output
PB7.GPIO_Label=LED_DTR5
PB7.Signal=GPIO_Output
PB8.GPIO_Label=CH3_2_2
PB8.Signal=GPIO_Output
PB9.GPIO_Label=CH3_3_1
PB9.Signal=GPIO_Output
PC0.GPIO_Label=CH4_1_1
PC0.Signal=GPIO_Output
PC1.GPIO_Label=CH4_1_2
PC1.Signal=GPIO_Output
PC10.GPIO_Label=CTL_CH3
PC10.Signal=S_TIM1_CH3
PC11.GPIO_Label=CTL_CH4
PC11.Signal=S_TIM1_CH4
PC12.GPIO_Label=CH4_3_1
PC12.Signal=GPIO_Output
PC13.GPIO_Label=CH4_3_2
PC13.Signal=GPIO_Output
PC2.GPIO_Label=SOUND1_DATA
PC2.Signal=GPIO_Output
PC3.GPIO_Label=SOUND1_CLK
PC3.Signal=GPIO_Output
PC4.GPIO_Label=ADC_CH4
PC4.Signal=ADC1_IN17
PC5.GPIO_Label=CH4_2_1
PC5.Signal=GPIO_Output
PC6.GPIO_Label=SOUND2_SD
PC6.Signal=GPIO_Output
PC7.GPIO_Label=CH4_2_2
PC7.Signal=GPIO_Output
PC8.GPIO_Label=CTL_CH1
PC8.Signal=S_TIM1_CH1
PC9.GPIO_Label=CTL_CH2
PC9.Signal=S_TIM1_CH2
PD0.GPIO_Label=CH1_1_1
PD0.Signal=GPIO_Output
PD1.GPIO_Label=FLASH_CLK
PD1.Signal=GPIO_Output
PD2.GPIO_Label=CH1_1_2
PD2.Signal=GPIO_Output
PD3.GPIO_Label=CH1_2_1
PD3.Signal=GPIO_Output
PD4.GPIO_Label=CH1_2_2
PD4.Signal=GPIO_Output
PD5.GPIO_Label=CH2_1_1
PD5.Signal=GPIO_Output
PD6.GPIO_Label=CH2_1_2
PD6.Signal=GPIO_Output
PD8.GPIO_Label=CH2_2_1
PD8.Signal=GPIO_Output
PD9.GPIO_Label=CH2_2_2
PD9.Signal=GPIO_Output

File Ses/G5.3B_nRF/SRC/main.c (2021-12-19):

#include <stdint.h>
#include <stdio.h>

//#include "nrf.h"

#include "nrf_delay.h"
#include "nrf_drv_systick.h"

#include "Module_Clock.h"
#include "Module_DebugLog.h"
#include "Module_GPIO.h"
#include "Module_Ble_Uart.h"
#include "board_config.h"

//void in_pin_handler(nrf_drv_gpiote_pin_t pin, nrf_gpiote_polarity_t action)
//{
//	switch (pin)
//	{
//		case BTN_1_PIN_NUMBER:
//		{
//			nrf_drv_gpiote_out_toggle(LED_2_PIN_NUMBER);
//			//nrf_drv_gpiote_out_set(LED_2_PIN_NUMBER);
//			//nrf_drv_systick_delay_ms(500);
//			//nrf_drv_gpiote_out_clear(LED_2_PIN_NUMBER);
//		}
//		break;
//	}
//}

int main()
{
	debugLog_init();
	nrf_clock_init();
	//nrf_drv_systick_init();
	//gpioe_init();
	//gpioe_output_set(LED_1_PIN_NUMBER, false);
	//gpioe_output_set(LED_2_PIN_NUMBER, false);
	//gpioe_input_set(BTN_1_PIN_NUMBER, true, 1, NRF_GPIO_PIN_PULLUP, in_pin_handler);

	ble_uart_ProgressExample();

	while (1) {}
}

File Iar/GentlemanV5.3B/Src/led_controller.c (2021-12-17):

/* Manual --------------------------------------------------------------------*/
/*
[기본사용절차]
1. led_controller.c 파일을 라이브러리(User)에 추가한다.
2. led_Dimming_Update() 50usec 주기로 호출하게 한다.(Ex.Tim3 Interrupt)
3. led_BlinkColUpdate() 10msec 주기로 호출하게 한다.(Ex.While(1){HAL_Delay(10);} in Main())

[동작형태간략 설명]
 - Dimming을 통해 R LED 7개, RGB LED 6개(이중 1개는 PCB외부에 존재)를 컨트롤한다.
 - 6개의 Section이 있어 1Section안에 R LED 1개, RGB LED 1개를 동시에 디밍한다.
 - 단, R LED D7번은 예외적으로 0번 Section에서 R LED D1과 RGB LED D1과 같이 컨트롤한다.
 - led_SetLevel을 통해 R LED D1~7이 On/Off 컨트롤 된다.
 - led_SetRGBCol를 통해 RGB LED D1~6이 Col 컨트롤 된다.
 - led_SetRGBGradationOn에 의해 RGB LED D1~6이 Gradation 된다.
 - led_SetRGBOn에 의해 RGB LED D1~6이 On/Off 된다.
 - Blink는 Gradation이 Off일 때에만 동작한다.

 [기타사항]
  - 호출 주기를 변경한 경우 그에 맞추어 내부코드 수정이 필요
  - BLINK 주기를 변경할 때는 LED_SECTION_DURATION을 수정
  - GRADATION 주기를 변경할 때는 led_BlinkColUpdate()의 계산식을 적절히 수정
*/

/* Private includes ----------------------------------------------------------*/
#include "led_controller.h"
#include "main.h"

/* Private variables ---------------------------------------------------------*/

#define LED_SECTION_DURATION 26	//=25+1 times (* 50usec)
#define LED_BLINK_DURATION 50	//=50 times (* 10msec)

GPIO_TypeDef *ledTRPorts[6] = { LED_TR1_GPIO_Port, LED_TR2_GPIO_Port, LED_TR3_GPIO_Port, LED_TR4_GPIO_Port, LED_TR5_GPIO_Port, LED_TR6_GPIO_Port, };
uint16_t ledTRPins[6] = { LED_TR1_Pin, LED_TR2_Pin, LED_TR3_Pin, LED_TR4_Pin, LED_TR5_Pin, LED_TR6_Pin, };

GPIO_TypeDef *ledDTRPorts[5] = { LED_DTR1_GPIO_Port, LED_DTR2_GPIO_Port, LED_DTR3_GPIO_Port, LED_DTR4_GPIO_Port, LED_DTR5_GPIO_Port, };
uint16_t ledDTRPins[5] = { LED_DTR1_Pin, LED_DTR2_Pin, LED_DTR3_Pin, LED_DTR4_Pin, LED_DTR5_Pin, };

uint8_t ledColRGB[6][3] = { {0, 0, 0,}, };
bool ledOnLv[7] = { false, };

bool ledOnRGB[6] = { true, true, true, true, true, true, };

uint8_t ledColRGBbase[7][3] = {
	{25, 0, 0,},	//Red
	{25, 13, 0,},	//Orange
	{17, 25, 0,},	//Yellow
	{0, 25, 1,},	//Green
	{0, 6, 25,},	//Blue
	{0, 25, 19,},	//Sky Blue
	{13, 0, 25,},	//Violet
};
//ColMaxValue는 25(= LED_SECTION_DURATION - 1)

uint8_t RGBColID = 0;
bool RGBGradationOn = true;
uint16_t RGBGradationTimer = 0;

bool BlinkSet = true;
int8_t BlinkLedID = -1;
uint16_t BlinkTimer = 0;



/* Private user code ---------------------------------------------------------*/

void led_Dimming_Update()
{
	// 설정에 따라 TR을 빠르게 On/Off하여 밝기를 조절한다.
	// 50usec 주기로 호출이 필요하다.

	static uint8_t DimTimer = 0xFF;
	static uint8_t ledSectioni = 5;
	static uint8_t ledDTRi = 0;

	if (DimTimer < LED_SECTION_DURATION)
	{
		//RGB LED 컨트롤
		for (ledDTRi = 0; ledDTRi < 3; ++ledDTRi)
		{
			HAL_GPIO_WritePin(ledDTRPorts[ledDTRi], ledDTRPins[ledDTRi],
				(GPIO_PinState)(ledColRGB[ledSectioni][ledDTRi] > DimTimer)
			);
		}

		if (DimTimer == 0)
		{
			//D1~6 LED 컨트롤
			if (ledOnLv[ledSectioni])
				HAL_GPIO_WritePin(ledDTRPorts[3], ledDTRPins[3], GPIO_PIN_SET);

			if (ledSectioni == 0)
			{
				//D7 LED 컨트롤
				if (ledOnLv[6])
					HAL_GPIO_WritePin(ledDTRPorts[4], ledDTRPins[4], GPIO_PIN_SET);
			}
		}

		++DimTimer;
	}
	else
	{
		// 타이머 갱신 및 초기화
		// 1 section 길이= SECTION_DURATION = (25+1)times * 50usec
		// +1은TR 변경후 휴식 딜레이. 없으면 led 잔상이 남는다.TR 반응속도 문제인듯 하다.
		DimTimer = 0;

		HAL_GPIO_WritePin(ledTRPorts[ledSectioni], ledTRPins[ledSectioni], GPIO_PIN_SET);
		++ledSectioni;

		if (ledSectioni > 5)
			ledSectioni = 0;

		for (ledDTRi = 0; ledDTRi < 5; ++ledDTRi)
		{
			HAL_GPIO_WritePin(ledDTRPorts[ledDTRi], ledDTRPins[ledDTRi], GPIO_PIN_RESET);
		}

		HAL_GPIO_WritePin(ledTRPorts[ledSectioni], ledTRPins[ledSectioni], GPIO_PIN_RESET);
	}
}

void led_BlinkColUpdate()
{
	// 설정에 따라 색상과 깜빡임을 업데이트한다. 
	// 10msec 주기로 호출이 필요하다.

	//그라데이션 업데이트
	if (RGBGradationOn)
	{
		uint8_t tmpCol[3];

		// 80 이란, 80 times * 10mesec = 0.8sec 주기
		// (-80~80) * (1/80) = -1~+1 -> 베이스변화량
		// (1/80) = 0.0125
		// * 0.0125 * 1.3 = 0.01625 -> 변화속도 x1.3 & 최대밝기 도달 후 유지기간
		// + 0.2 -> 최소밝기 지정 & 최대밝기 도달 후 유지기간
		float colRate = RGBGradationTimer - 80;
		if (colRate < 0) { colRate *= -1; }
		colRate = colRate * 0.01625f + 0.2f;
		if (colRate > 1.f) { colRate = 1.f; }

		++RGBGradationTimer;
		if (RGBGradationTimer > 160)
			RGBGradationTimer = 0;

		tmpCol[0] = (int)(ledColRGBbase[RGBColID][0] * colRate);
		tmpCol[1] = (int)(ledColRGBbase[RGBColID][1] * colRate);
		tmpCol[2] = (int)(ledColRGBbase[RGBColID][2] * colRate);

		for (uint8_t i = 0; i < 6; i++)
		{
			if (ledOnRGB[i])
			{
				ledColRGB[i][0] = tmpCol[0];
				ledColRGB[i][1] = tmpCol[1];
				ledColRGB[i][2] = tmpCol[2];
			}
			else
			{
				ledColRGB[i][0] = ledColRGB[i][1] = ledColRGB[i][2] = 0;
			}
		}
	}
	else
	{
		//깜빡임 업데이트
		if (BlinkLedID > -1)
		{
			if (BlinkTimer >= LED_BLINK_DURATION)
			{
				BlinkTimer = 0;
				BlinkSet = !BlinkSet;

				ledOnLv[BlinkLedID] = BlinkSet;
			}
		}

		++BlinkTimer;
	}

}

void led_SetLevel(uint8_t setLevel)
{
	BlinkTimer = 0;
	BlinkLedID = -1;
	BlinkSet = true;

	uint8_t OnLedCnt = 0;

	//MaxLevel개수 예외처리
	if (setLevel > 14)
		setLevel = 14;

	//켜져야 될 LED 개수
	//OnLedCnt = (utin8_t)((setLevel + 1) / 2);
	OnLedCnt = ((setLevel + 1) >> 1);

	if (OnLedCnt > 0)
	{
		//비트연산을 통해 홀짝을 확인
		if (setLevel & 1 == 1)
		{
			//홀수인 경우에는 블링크 시스템 필요
			//블링크 될 LED ID를 선정
			BlinkLedID = OnLedCnt - 1;
		}

		//Level LED On
		for (uint8_t i = 0; i < OnLedCnt; i++)
		{
			ledOnLv[i] = true;
		}
	}

	for (uint8_t i = OnLedCnt; i < 7; i++)
	{
		ledOnLv[i] = false;
	}
}

void led_SetRGBCol(uint8_t setRGBColID)
{
	RGBGradationTimer = 0;
	RGBColID = setRGBColID;

	for (uint8_t i = 0; i < 6; i++)
	{
		ledColRGB[i][0] = ledColRGBbase[RGBColID][0];
		ledColRGB[i][1] = ledColRGBbase[RGBColID][1];
		ledColRGB[i][2] = ledColRGBbase[RGBColID][2];
	}
}

void led_SetRGBOn(uint8_t setRGBID, bool SetEnable)
{

	if (ledOnRGB[setRGBID] == SetEnable)
		return;

	ledOnRGB[setRGBID] = SetEnable;
        

	if (ledOnRGB[setRGBID])
	{
		ledColRGB[setRGBID][0] = ledColRGBbase[RGBColID][0];
		ledColRGB[setRGBID][1] = ledColRGBbase[RGBColID][1];
		ledColRGB[setRGBID][2] = ledColRGBbase[RGBColID][2];
	}
	else
	{
		ledColRGB[setRGBID][0] = ledColRGB[setRGBID][1] = ledColRGB[setRGBID][2] = 0;
	}
}

void led_SetRGBGradationOn(bool SetEnable)
{
	RGBGradationOn = SetEnable;
	if (!RGBGradationOn)
		led_SetRGBCol(RGBColID);
}

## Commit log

2021-10-10 KSG : 라이선스 및 리드미 파일 제작
2021-10-10 KSG : KiCad프로젝트 생성 및 무시규칙, 유틸리티 업데이트
    [KiCAD_Gentlman_V6.3.kicad_pcb, KiCAD_Gentlman_V6.3.sch]
2021-10-18 KSG : 블루투스 모듈 데이터시트 업로드
2021-10-18 KSG : 잘못된 이름의 파일 제거
    [KiCAD_Gentlman_V6.3.kicad_pcb, KiCAD_Gentlman_V6.3.sch]
2021-10-18 KSG : KICAD 연습(G070RB 심볼 및 풋프린트 얹기)
    [201228 CPP-093AB(demo2).xlsx, KiCAD_Gentlman_V5.3.kicad_pcb, KiCAD_Gentlman_V5.3.sch]
2021-10-19 KSG : 일부파일 폴더 위치 변경
    [201228 CPP-093AB(demo2).xlsx]
2021-10-19 KSG : KICAD 라이브러리 대량 업데이트 및 회로도 제작 연습
    [KiCAD_Gentlman_V5.3.sch, Main.sch, OutPulsePart.sch]
2021-10-20 KSG : 뉴클레오 UART 블루투스 통신 테스트 완료(휴대폰과 통신)
2021-10-28 KSG : 블루투스 모듈 오리지널 Hex파일 백업
2021-10-29 KSG : nRF5_SDK 업로드
2021-10-29 KSG : 커스텀 프로젝트 제작(GPIO, Dealy 구현 및 테스트)
2021-10-29 KSG : GPIOE 코드 구현
2021-10-29 KSG : doxy파일 구성 및 example ignore 구성
2021-10-29 KSG : Ses 셋팅 최적화 및 설정파일저장, 소스파일 최적화
2021-10-29 KSG : systick_delay적용 및 sdk_config wizard 설정
2021-10-30 KSG : 시스템틱 미싱코드 추가 및 클락 시스템 제어 코드 테스트
2021-10-30 KSG : 핀번호 관리 헤더 추가 및 LED 2개로 내용 수정
    [board_config.h, main.c]
2021-10-31 KSG : UART 테스트 완료(Config중 UART_LEGACY 설정에 문제가 있음 확인 예정)
2021-10-31 KSG : UART 구축 완료
2021-11-02 KSG : sdk_config에서 clock설정이 잘못되어 있는 부분 수정. 또한 일부 오타수정 및 정렬 진행.
2021-11-02 KSG : 보드 핀번호 변경 및 기존 모듈 기능 최적화 및 라인정렬
2021-11-02 KSG : UART 최적화(UART 비연결시에도 동작되도록 작동)
2021-11-02 KSG : RSSI 테스트 완료
2021-11-02 KSG : 라디오 모듈 제작 및 테스트 완료
2021-11-05 KSG : NRF로그 시스템 추가, flash_placement수정, 소프트디바이스 적용
    [main.c]
2021-11-06 KSG : SES 셋팅 설정 백업
2021-11-06 KSG : 셋팅 깨끗하게 하여 최적화
2021-11-06 KSG : SES 라이선스 추가
2021-11-06 KSG : 셋팅 최적화. 불필요 구문 삭제. 빌드시 내역 표시 기능 설정.
2021-11-06 KSG : BLE_UART 동작 코드 완료. 테스트 완료.(최적화 필요)
2021-11-13 KSG : V5.3 회로도 초본 완성(검토 필요) 일부 부품 데이터시트 추가
    [KiCAD_Gentlman_V5.3.sch, Main.sch, OutPulsePart.sch]
2021-11-18 KSG : V5.3 회로도 완성, 심볼 정보 업데이트 완료(데이터시트 및 풋프린트 등), 기존 BOM과 일치 완료
    [201228 CPP-093AB(demo2).xlsx, 201228 CPP-093AB(demo2)_BOM.xlsx, KiCAD_Gentlman_V5.3.kicad_pcb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]
2021-11-18 KSG : 블루투스 회로도 작성 완료 (풋프린트 및 데이터시트 업데이트 완료)
    [201228 CPP-093AB(demo2)_BOM.xlsx, Bluetooth.sch, KiCAD_Gentlman_V5.3.sch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]
2021-11-19 KSG : 반이중통신용 회로도 구성 완료
    [Bluetooth.sch, Main.sch]
2021-11-23 KSG : 회로도 에 nRF52 DC-DC 레귤레이터 추가
    [Bluetooth.sch]
2021-12-02 KSG : V5.3B용으로 회로도 수정 및 PCB 아트웤 완료.(샘플PCB주문됨)
    [Bluetooth.sch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]
2021-12-17 KSG : LM1117 데이터 시트 업데이트
2021-12-17 KSG : 테스트용 V5.3B IAR 펌웨어 소스 업로드(V5.2G기반 베이스)
2021-12-18 KSG : 보드 수정(크리스탈 배치 문제, 점퍼추가, 이름위치오기수정, IC1번핀표시)
    [Bluetooth.sch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]
2021-12-18 KSG : G5.3B_nRF 프로젝트 생성 및 nRF52832 클린 프로젝트 생성
2021-12-19 KSG : nRF52832 UART_BLE 동작버전 업로드
2021-12-19 KSG : nRF52810 프로젝트 생성 및 동작 확인.

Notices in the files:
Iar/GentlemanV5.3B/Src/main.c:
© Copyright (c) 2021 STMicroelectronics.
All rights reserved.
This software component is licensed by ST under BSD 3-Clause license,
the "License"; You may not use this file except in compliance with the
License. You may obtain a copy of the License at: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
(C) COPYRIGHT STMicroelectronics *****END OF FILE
